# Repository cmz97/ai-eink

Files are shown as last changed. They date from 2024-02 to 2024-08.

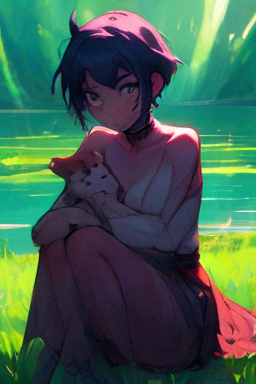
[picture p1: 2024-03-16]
temp-anime-flexible.png

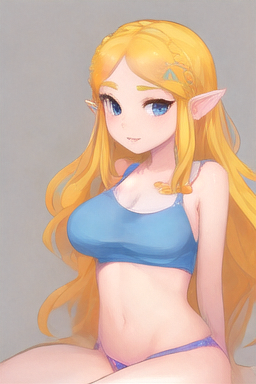
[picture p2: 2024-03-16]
temp-anime-zelda.png

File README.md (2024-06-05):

# ai-eink

# System 
sudo apt-get install sysstat

# Device Tree Overlay
force_turbo=1
dtoverlay=uart3

# NFC
NFC Driver: https://github.com/2pecshy/eeprom-ST25DV-linux-driver
sudo apt install -y python3-libcamera python3-kms++ libcap-dev

# Drivers
## Camera 
sudo wget https://datasheets.raspberrypi.org/cmio/dt-blob-cam1.bin -O /boot/dt-blob.bin
libcamera-still -q 80 -o test.jpg

For OS Lite 
Open Terminal and enter "sudo nano /boot/config.txt"
Scroll down to the line that reads "camera_auto_detect=1" and change it to "camera_auto_detect=0"
On the next line, enter "dtoverlay=imx219"
Reboot

## Speakers
https://github.com/HinTak/seeed-voicecard
sudo aplay -Dhw:0 test.wav
sudo arecord -D hw:0,0 -f S32_LE -r 16000 -c 2 test.wav
https://www.waveshare.com/wiki/WM8960_Audio_HAT
sudo alsactl store

## Pi-PICO
ampy --port /dev/tty.usbmodem112401 put main.py

## Radxa
sudo apt-get install python3-dev spidev
sudo apt-get update
sudo apt-get install python3-libgpiod

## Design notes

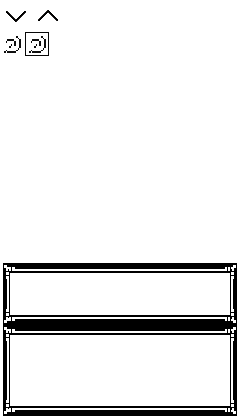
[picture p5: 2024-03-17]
ui_sheet.png

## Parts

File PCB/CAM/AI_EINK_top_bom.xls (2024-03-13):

Comment | Designator | Footprint | LCSC Part #
 | J2 JP6 SJ1 SJ2 SJ3 SJ4 SJ5 SJ6
MK-12C02-G020 | S1
DNP SPW2430HR5H-B | LEFTMIC RIGHTMIC
0.01 | R12 | 1206
0.1uF | C4 C16 C18 | 0805_10MGAP
0.1uF | C25 C27 C47 C48 C49 C50 C51 C58 | 0603-NO
0.47 | R9 | RESC1608X60
0.47uF | C20 | 0603-CAP
1.0uF | C19 | 0603-CAP
1.0uF | C22 | 1206-CAP
1.0uF | C30 | 0603-NO
1.1k | R7 R21 | 0603-RES
1.87M | R3 | 0805-NO
1.87M (TPA2005D1DRBR) | R1 | _0805MP
1K | R5 R20 | 0805-NO
1K | R23 | 0603-RES
1k | R8 R10 R28 | R0603
1nF | C36 C37 C38 C39 C40 | 603
1uF | C5 C8 C9 C10 C11 C12 C13 C14 C15 | CAPC1608X85
2.2uF | C2 | 0805-NO
2.2uF+ | C66 | 0805-NO
4.7K | R15 R18 | 0603-RES
4.7uF/50V | C17 | 0805_10MGAP
5VBOOST | LED2 | CHIPLED_0805_NOOUTLINE
6.8uH | L1 | INDUCTOR_5X5MM_TDK_VLC5045
10K | R11 | RESC1608X60
10K | R14 | 0603-NO
10K | R29 R33 | 0603-RES
10uF | C1 C3 C7 | 0805-NO
10uF | C21 C23 | 0805-CAP
10uF | C24 C26 C31 C32 C33 C34 C35 C45 C46 C56 C57 C65 | 0805-NO
24MHz 3.3V Oscillator | OSC1 | OSC_3.2X2.5MM
33pF | C52 C53 C54 C55 | 0603-NO
100k | R24 R31 | 0603-RES
100pF | C63 C64 | 0603-NO
100uF | C6 | C1210
120o | FB9 FB10 | 0805-NO
180 | R22 | 0603-RES
200K | R4 R13 | 0805-NO
340K (RTT053403FTP) | R2 | _0805MP
590 | R6 R19 | 0603-RES
524372471 | J3 | CON_524372471_MOL
ACT (MHT192JGCT) | D1 | LED-0603@1
ASPI-0403S-100M-T | L2 | IND_ASPI-0403S-100M-T
BLM18HE152SN1D | FL1 FL2 | BEADC1608X95N
BQ24075 | U4 | PVQFN-N16
BQ27441DRZR-G1A | U3 | PDSO-N12
CHARGING FC-1608B1-470 | D5 | LED-0603
CMS-18138A-SP | LS1 | CUI_CMS-18138A-SP
DF30FC-24DP-0.4V(81) | OV5647 | DF30FC-24DP
DF40C-100DS-0.4V(51) | RPI-CM1 | RPI-CM4
DF40C-100DS-0.4V(51) | RPI-CM1-2 | RPI-CM4
ECS-3225MV | OSC2 | OSC_3.2X2.5MM
FERRITE | FB4 | 0805-NO
Ferrite | FB3 | 0805-NO
MBR0530 | D2 D3 D4 | SOD3716X135N
MC74VHC1G14DFT1G | U2 | SOT65P210X110-5N
MMUN2133LT1G | T1 | SC59-BEC
NFC_ANTENNA_25X15 | ANT1 | NFCANT_25X15
PMIC | D6 | LED-0603
SI1308EDL-T1-GE3 | Q1 | SOT65P210X110-3N
ST25DVXX_TSSOP | RF1 | TSSOP8-4.4MM
SYS_POW (19-213/Y2C-CQ2R2L/3T(CY)) | LED3 | LED-0603
TEST-POINT3 | GND GND13 GND22 GND25 GND26 GND27 RPIBOOT RPIBOOT1 RPIBOOT2 RPIBOOT3 RPIBOOT4 RPIBOOT5 | PAD.03X.03
TLV74315 | U6 | SOT23-5
TLV74328 | U5 | SOT23-5
TPS61090RSAR | U1 | PVQFN-16
WM8960 | IC3 | QFN32_5MM
XL-2012VRC | LOW_BATT | CHIPLED_0805_NOOUTLINE

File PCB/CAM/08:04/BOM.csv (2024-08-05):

Comment | Designator | Footprint | LCSC Part #
1uF | C5 C14 | CAPC1005X60
10K | R18 | RESC1005X40
10k | R4 | RESC1005X40
10uF | C8 C9 C17 | CAPC1005X60
22uF | C1 | CAPC1005X60
22uF | C2 | CAPC1608X85
22uF | C3 | CAPC1005X60
100K | R1 R3 | RESC1005X40
120pF | C4 | CAPC1005X60
450K | R2 | RESC1005X40
ESP32-S3-WROOM | U5 | S3-WROOM32
KLM8G1GETF-B041KLMBG2JENB-B041_SAM | U1 | KLMBG2JENB-B041_SAM
MIC5504-1.8YMT-TRTDFN1010-4LD-PL-2_MCH | U2 | TDFN1010-4LD-PL-2_MCH
RKB2 | SW1 SW2 | BTN_RKB2_4.6X2.8
SDER041H-2R2MS | L1 | INDUCTOR_4X4MM_SRP0415
SM04B-SRSS-TBCONN_SM04B-SRSS-TB_JST | J2 J3 | CONN_SM04B-SRSS-TB_JST
SM08B-SRSS-TB(LF)(SN)CONN_SM08B-SRSS-TB(LF)(SN)_JST | J1 | CONN_SM08B-SRSS-TB(LF)(SN)_JST
TPS6282X | IC2 | VSON_6
green | D1 | CHIPLED_0603_NOOUTLINE
DF40C-100DP-0.4V(51) | JA JB | HIROSE_DF40C-100DP-0.4V(51)
DNP | TP_1V8 TP_3V3 TP_5V TP_DATA0 TP_EMMC_CLK TP_EMMC_CMD TP_GND | PAD.03X.03

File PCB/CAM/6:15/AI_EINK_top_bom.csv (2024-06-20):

Comment | Designator | Footprint | LCSC Part #
0.01 | R12 | 1206
0.1uF | C4 C24 C31 | CAPC1005X60
0.1uF | C42 | CAPC1608X85
0.1uF | C43 C44 C47 C48 C49 C50 C58 C67 C69 C71 C72 C73 C74 C77 | CAPC1005X60
0.47 | R9 | RESC1005X40
0.47uF | C20 | CAPC1005X60
1-2199119-5 OR C841645 | M.2KEYM(NGFF) | TE_1-2199119-5
1.0uF | C19 C30 C75 C76 | CAPC1005X60
1.1k | R7 | RESC1005X40
1.87M | R3 | RESC1005X40
1.87M (TPA2005D1DRBR) | R1 | RESC1005X40
1K | R5 R14 R20 R23 | RESC1005X40
1k | R8 R10 R34 R35 | RESC1005X40
1uF | C5 C8 C9 C10 C11 C12 C13 C14 C15 C16 C34 C35 | CAPC1005X60
2.2uF | C2 | CAPC1005X60
2.2uF+ | C66 | CAPC1005X60
4.7K | R15 R18 R25 R26 R40 R42 | RESC1005X40
4.7k | R38 | RESC1005X40
4.7uF | C18 | CAPC1608X85
4.7uF | C29 | CAPC1005X60
4.7uF/50V | C17 | CAPC1005X60
5.1K | R19 | RESC1005X40
5.1k | R21 | RESC1005X40
6.8uH C36410 | L1 | INDUCTOR_5X5MM_TDK_VLC5045
6.57k | R44 | RESC1005X40
10K | R11 R33 R43 | RESC1005X40
10k | R16 R17 R27 R28 R37 R39 | RESC1005X40
10uF | C1 C3 C7 C21 C22 C23 C26 C28 C32 C33 C36 C40 C45 C46 C53 C59 C60 C61 C62 C65 C68 C79 C80 | CAPC1005X60
15p | C82 C83 | CAPC1005X60
27 | R31 R32 | RESC1005X40
27pF | C27 | CAPC1005X60
36k | R30 | RESC1005X40
47K | R41 | RESC1005X40
100k | R24 | RESC1005X40
100pF | C63 C64 | CAPC1005X60
100uF | C6 C25 | C1210
180 | R22 | RESC1005X40
200K | R4 R13 R36 | RESC1005X40
340K (RTT053403FTP) | R2 | RESC1005X40
590 | R6 | RESC1005X40
524372471 | EINK_524352471 | CON_524372471_MOL
ABM8-272-T3 | Y1 | ABM8272T3
ACT (MHT192JGCT) | D1 | LED-0603@1
AP2112-3.3K | U10 U11 U15 | SOT23-5
BM04B-SRSS-TBCONN4_BM04B-SRSS_JST | H2 J4 J5 | CONN4_BM04B-SRSS_JST
BQ24075 | U4 | PVQFN-N16
BQ27441DRZR-G1A | U3 | PDSO-N12
C233266 | U12 | XDCR_SPU0410LR5H-QB
C262642 | CAMERA | CON_524372271_MOL
C393939 | J2 | USB-C-16P
CHARGING FC-1608B1-470 | D5 | LED-0603
CMS-18138A-SP | LS1 | CUI_CMS-18138A-SP
DF40C-100DS-0.4V(51) | RPI-CM1 | RPI-CM4
DMG2307L | Q2 | SOT96P240X110-3N
DNP | GND13 GND26 GND27 GND34 RPIBOOT RPIBOOT1 RPIBOOT2 RPIBOOT3 RPIBOOT4 | PAD.03X.03
DNP | SJ1 SJ6 | PAD-JUMPER-2-NC_BY_TRACE_YES_SILK
DNP | USB_BOOT_N | PAD.03X.03
DRV2605LDGSR | U25 | SOP50P490X110-10N
ECS-3225MV | OSC2 | OSC_3.2X2.5MM
EMC2301-1-ACZL-TRMSOP8_MC_MCH-L | U9 | MSOP8_MC_MCH-L
EVQ-P7A01P | BUD BUP BUS | SW_EVQ-P7A01P
FERRITE_BEAD | FB1 FB2 FB3 FB5 | BEADC1608X95N
FNR5012S100MT 10uH | L3 | IND_LQH5BPN2R2NT0L
LED_RED | LED2 LOW_BATT | LEDC1608X65N_RND-R
LIS3MDL | IC1 | LGA12_2X2MM
LSM6DS3 | U6 | LGA-14L
MBR0530 | D2 D3 D4 | SOD3716X135N
MC74VHC1G14DFT1G | U2 | SOT65P210X110-5N
MC74VHC1G14DFT1G OR C66196 | U5 | SOT65P210X110-5N
MMUN2133LT1G | T1 | SC59-BEC
NMOS_C7465427 | Q3 Q4 | SOT23
OPA344 | U14 | SOT23-5
PMIC | D6 D7 | LED-0603
RP2040TR13QFN56_7X7_RPI | C2040 | QFN56_7X7_RPI
SI1308EDL-T1-GE3 | Q1 | SOT65P210X110-3N
SM03B-SRSS-TBCONN_SM03B-SRSS-TB_JST | J1 | CONN_SM03B-SRSS-TB_JST
SM04B-SRSS-TBCONN_SM04B-SRSS-TB_JST | J6 | CONN_SM04B-SRSS-TB_JST
SN74LVC244ARWPRRWP0020A | U7 | RWP0020A
SYS_POW (19-213/Y2C-CQ2R2L/3T(CY)) | LED3 | LED-0603
TEST-POINT3 | RPIBOOT5 | PAD.03X.03
TPD1E1B04DPYRDPY2_TEX | U17 U18 U19 U20 U21 U22 U23 U24 | DPY2_TEX
TPD4EUSB30DQARDQA10 | U13 | DQA10
TPS61092RSAR | U1 | PVQFN-16
TS3USB30RSWR | USB2.0MUX | 10-UFQFN
W25Q16JVUXIQ_TR | U16 | PSON50P300X200X60-9N
WM8960 | IC3 | QFN32_5MM

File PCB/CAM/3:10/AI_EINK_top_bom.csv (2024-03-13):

Comment | Designator | Footprint | LCSC Part #
0.01 | R12 | 1206
0.1uF | C4 C27 C42 C43 C44 C47 C48 C49 C50 C58 C67 C69 C70 C71 C72 C73 C74 C77 C78 C81 | CAPC1608X85
0.47 | R9 | R0603
0.47uF | C20 | CAPC1608X85
1.0uF | C19 C22 C25 C30 C75 C76 | CAPC1608X85
1.1k | R7 | R0603
1.87M | R3 | R0603
1.87M (TPA2005D1DRBR) | R1 | R0603
1K | R5 R14 R20 R23 | R0603
1k | R8 R10 R34 R35 | R0603
1uF | C5 C8 C9 C10 C11 C12 C13 C14 C15 C16 | CAPC1608X85
2.2uF | C2 | CAPC1608X85
2.2uF+ | C66 | CAPC1608X85
2.5A/30V | Q2 | SOT23-3
4.7K | R15 R18 | R0603
4.7uF | C18 | CAPC1608X85
4.7uF/50V | C17 | CAPC1608X85
5VBOOST | LED2 | CHIPLED_0805_NOOUTLINE
6.8uH | L1 | INDUCTOR_5X5MM_TDK_VLC5045
10K | R11 R29 R33 | R0603
10k | R16 R17 R28 | R0603
10uF | C1 C3 C7 C21 C23 C24 C26 C28 C29 C31 C32 C33 C34 C35 C36 C37 C38 C39 C45 C46 C57 C59 C60 C61 C62 C65 C68 C79 C80 | CAPC1608X85
15p | C82 C83 | CAPC1608X85
24MHz 3.3V Oscillator | OSC1 | OSC_3.2X2.5MM
27 | R31 R32 | R0603
33pF | C52 C54 | CAPC1608X85
36k | R30 | R0603
100k | R24 | R0603
100pF | C63 C64 | CAPC1608X85
100uF | C6 | C1210
120o | FB9 FB10 | 0805-NO
180 | R22 | R0603
200K | R4 R13 R36 R37 | R0603
340K (RTT053403FTP) | R2 | R0603
590 | R6 | R0603
524372471 | J3 | CON_524372471_MOL
ABM8-272-T3 | Y1 | ABM8272T3
ACT (MHT192JGCT) | D1 | LED-0603@1
AP2112-3.3K | U10 U11 | SOT23-5
ASPI-0403S-100M-T | L2 | IND_ASPI-0403S-100M-T
BLM18HE152SN1D | FL3 FL4 FL5 | BEADC1608X95N
BM04B-GHS-TBT(LF)(SN)(N) | J1 | JST_BM04B-GHS-TBT(LF)(SN)(N)
BQ24075 | U4 | PVQFN-N16
BQ27441DRZR-G1A | U3 | PDSO-N12
C393939 | J2 | USB-C-16P
C963206 | S1 | SWITCH-SPST-SMD-A
CHARGING FC-1608B1-470 | D5 | LED-0603
CMS-18138A-SP | LS1 | CUI_CMS-18138A-SP
DF30FC-24DS-0.4V(82)CONN_DF30FC-24DS-0.4V(82)_HIR | OV5674 | CONN_DF30FC-24DS-0.4V(82)_HIR
DF40C-100DS-0.4V(51) | RPI-CM1 | RPI-CM4
DF40C-100DS-0.4V(51) | RPI-CM2 | RPI-CM4
DNP | GND GND13 GND22 GND25 GND26 GND27 GND34 RPIBOOT RPIBOOT1 RPIBOOT2 RPIBOOT3 RPIBOOT4 | PAD.03X.03
DNP | SJ1 | PAD-JUMPER-2-NC_BY_TRACE_YES_SILK
DNP | SJ2 SJ3 | PAD-JUMPER-3-2OF3_NC_BY_TRACE_YES_SILK_FULL_BOX
DNP | SJ6 | PAD-JUMPER-2-NC_BY_TRACE_YES_SILK
DNP | USB_BOOT_N | PAD.03X.03
ECS-3225MV | OSC2 | OSC_3.2X2.5MM
EMC2301-1-ACZL-TRMSOP8_MC_MCH-L | U9 | MSOP8_MC_MCH-L
Ferrite | FB2 | 0805
Ferrite | FB3 | 0805-NO
Ferrite | FB5 | 0805
MBR0530 | D2 D3 D4 | SOD3716X135N
MC74VHC1G14DFT1G | U2 | SOT65P210X110-5N
MMUN2133LT1G | T1 | SC59-BEC
NFC_ANTENNA_25X15 | ANT1 | NFCANT_25X15
PMIC | D6 D7 | LED-0603
RP2040TR13QFN56_7X7_RPI | C2040 | QFN56_7X7_RPI
S2B-PH-SM4-TB | JP6 | JST-2-SMD
SI1308EDL-T1-GE3 | Q1 | SOT65P210X110-3N
SPU0410LR5H-QB | U12 | XDCR_SPU0410LR5H-QB
ST25DV64K-IER6S3SOIC_IER6S3_STM | U8 | SOIC_IER6S3_STM
SYS_POW (19-213/Y2C-CQ2R2L/3T(CY)) | LED3 | LED-0603
TEST-POINT3 | RPIBOOT5 | PAD.03X.03
TLV74315 | U6 | SOT23-5
TLV74318PDBVRDBV0005A_L | U7 | DBV0005A_L
TLV74328 | U5 | SOT23-5
TPS61090RSAR | U1 | PVQFN-16
W25Q128JVBIQTFBGA_128JVBIQ_WIN | SPI_FLASH_SAM | TFBGA_128JVBIQ_WIN
WM8960 | IC3 | QFN32_5MM
XL-2012VRC | LOW_BATT | CHIPLED_0805_NOOUTLINE

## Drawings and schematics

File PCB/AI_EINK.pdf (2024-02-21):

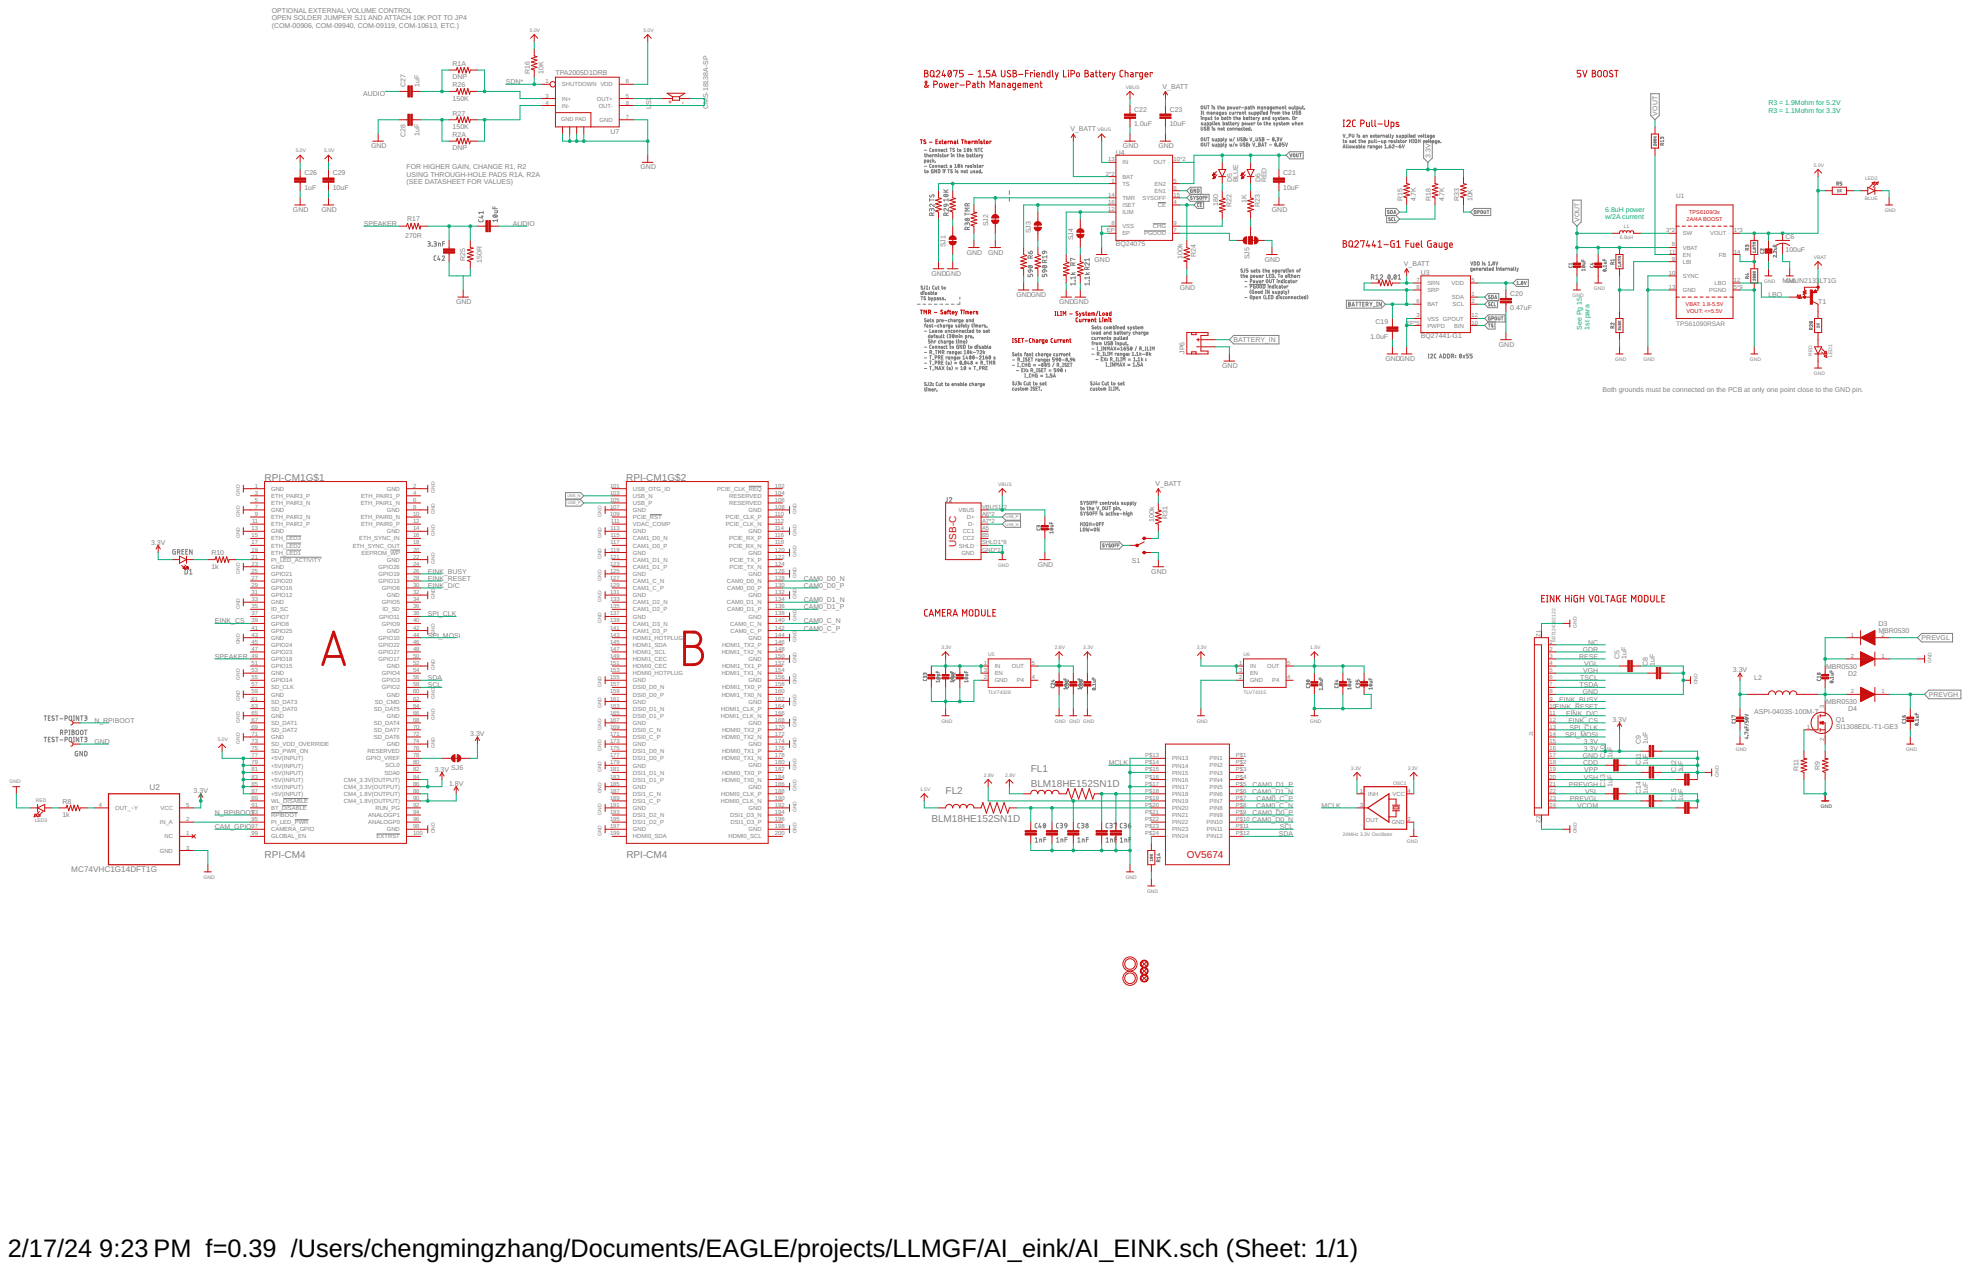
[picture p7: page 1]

OPEN SOLDER JUMPER SJ1 AND ATTACH 10K POT TO JP4 OPTIONAL EXTERNAL VOLUME CONTROL
(COM-00906, COM-09940, COM-09119, COM-10613, ETC.)

FOR HIGHER GAIN, CHANGE R1, R2 USING THROUGH-HOLE PADS R1A, R2A
(SEE DATASHEET FOR VALUES)

Both grounds must be connected on the PCB at only one point close to the GND pin.

GND GND GND GND GND GND GND GND GND GND 1k

GND GND GND GND GND GND GND GND GND GND GND

GND GND GND GND GND GND GND

GND GND GND GND GND GND GND GND

2/17/24 9:23 PM f=0.39 /Users/chengmingzhang/Documents/EAGLE/projects/LLMGF/AI_eink/AI_EINK.sch (Sheet: 1/1)

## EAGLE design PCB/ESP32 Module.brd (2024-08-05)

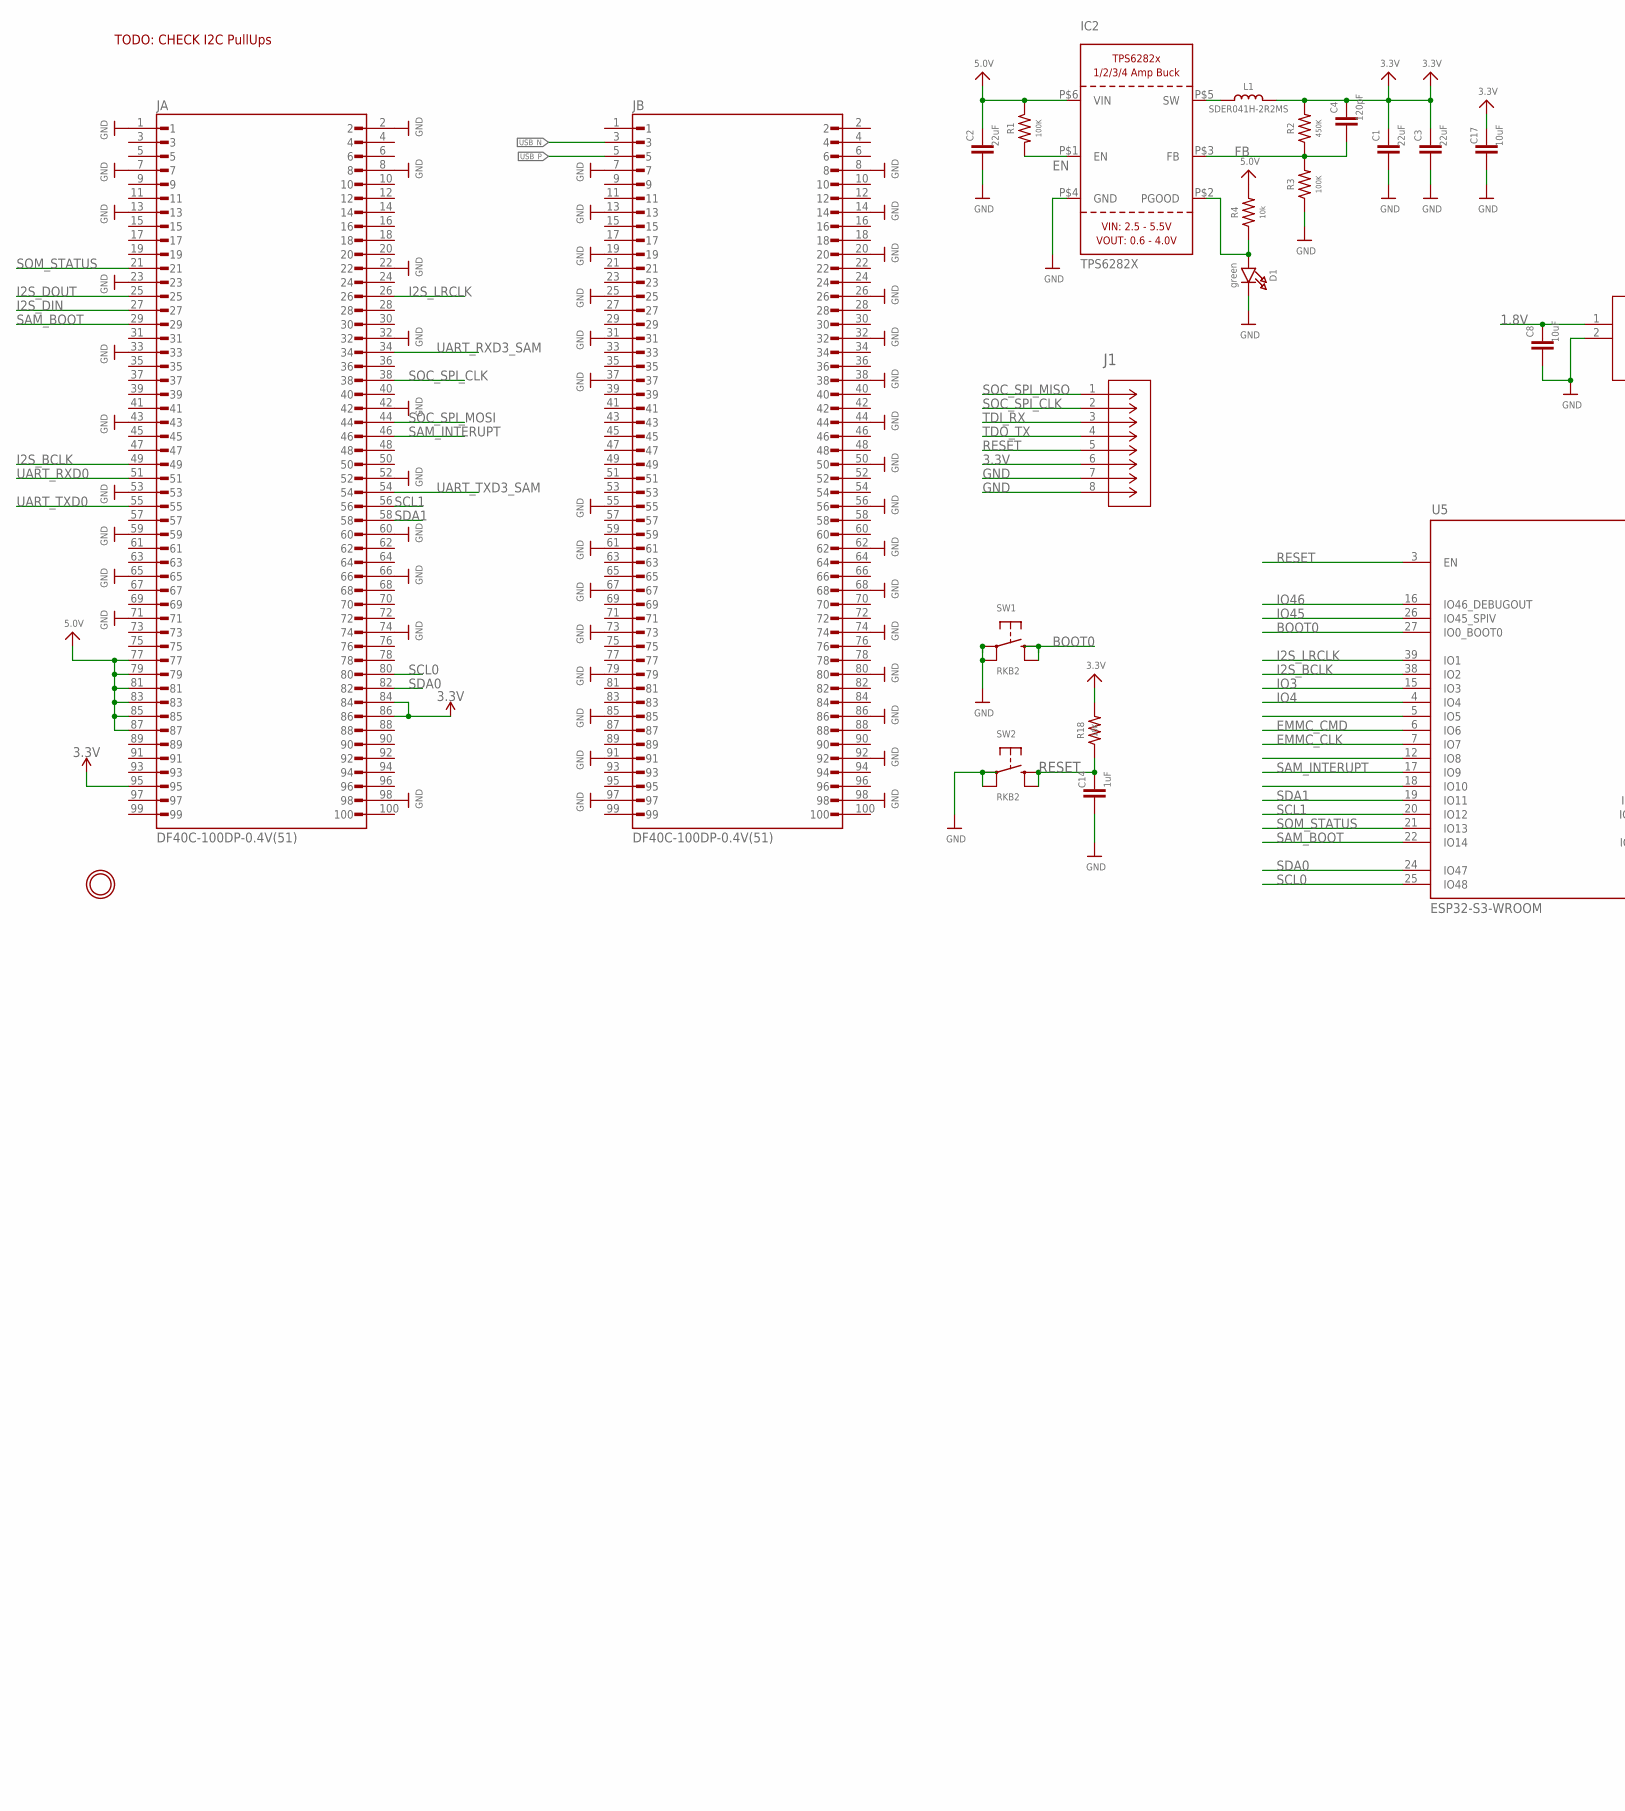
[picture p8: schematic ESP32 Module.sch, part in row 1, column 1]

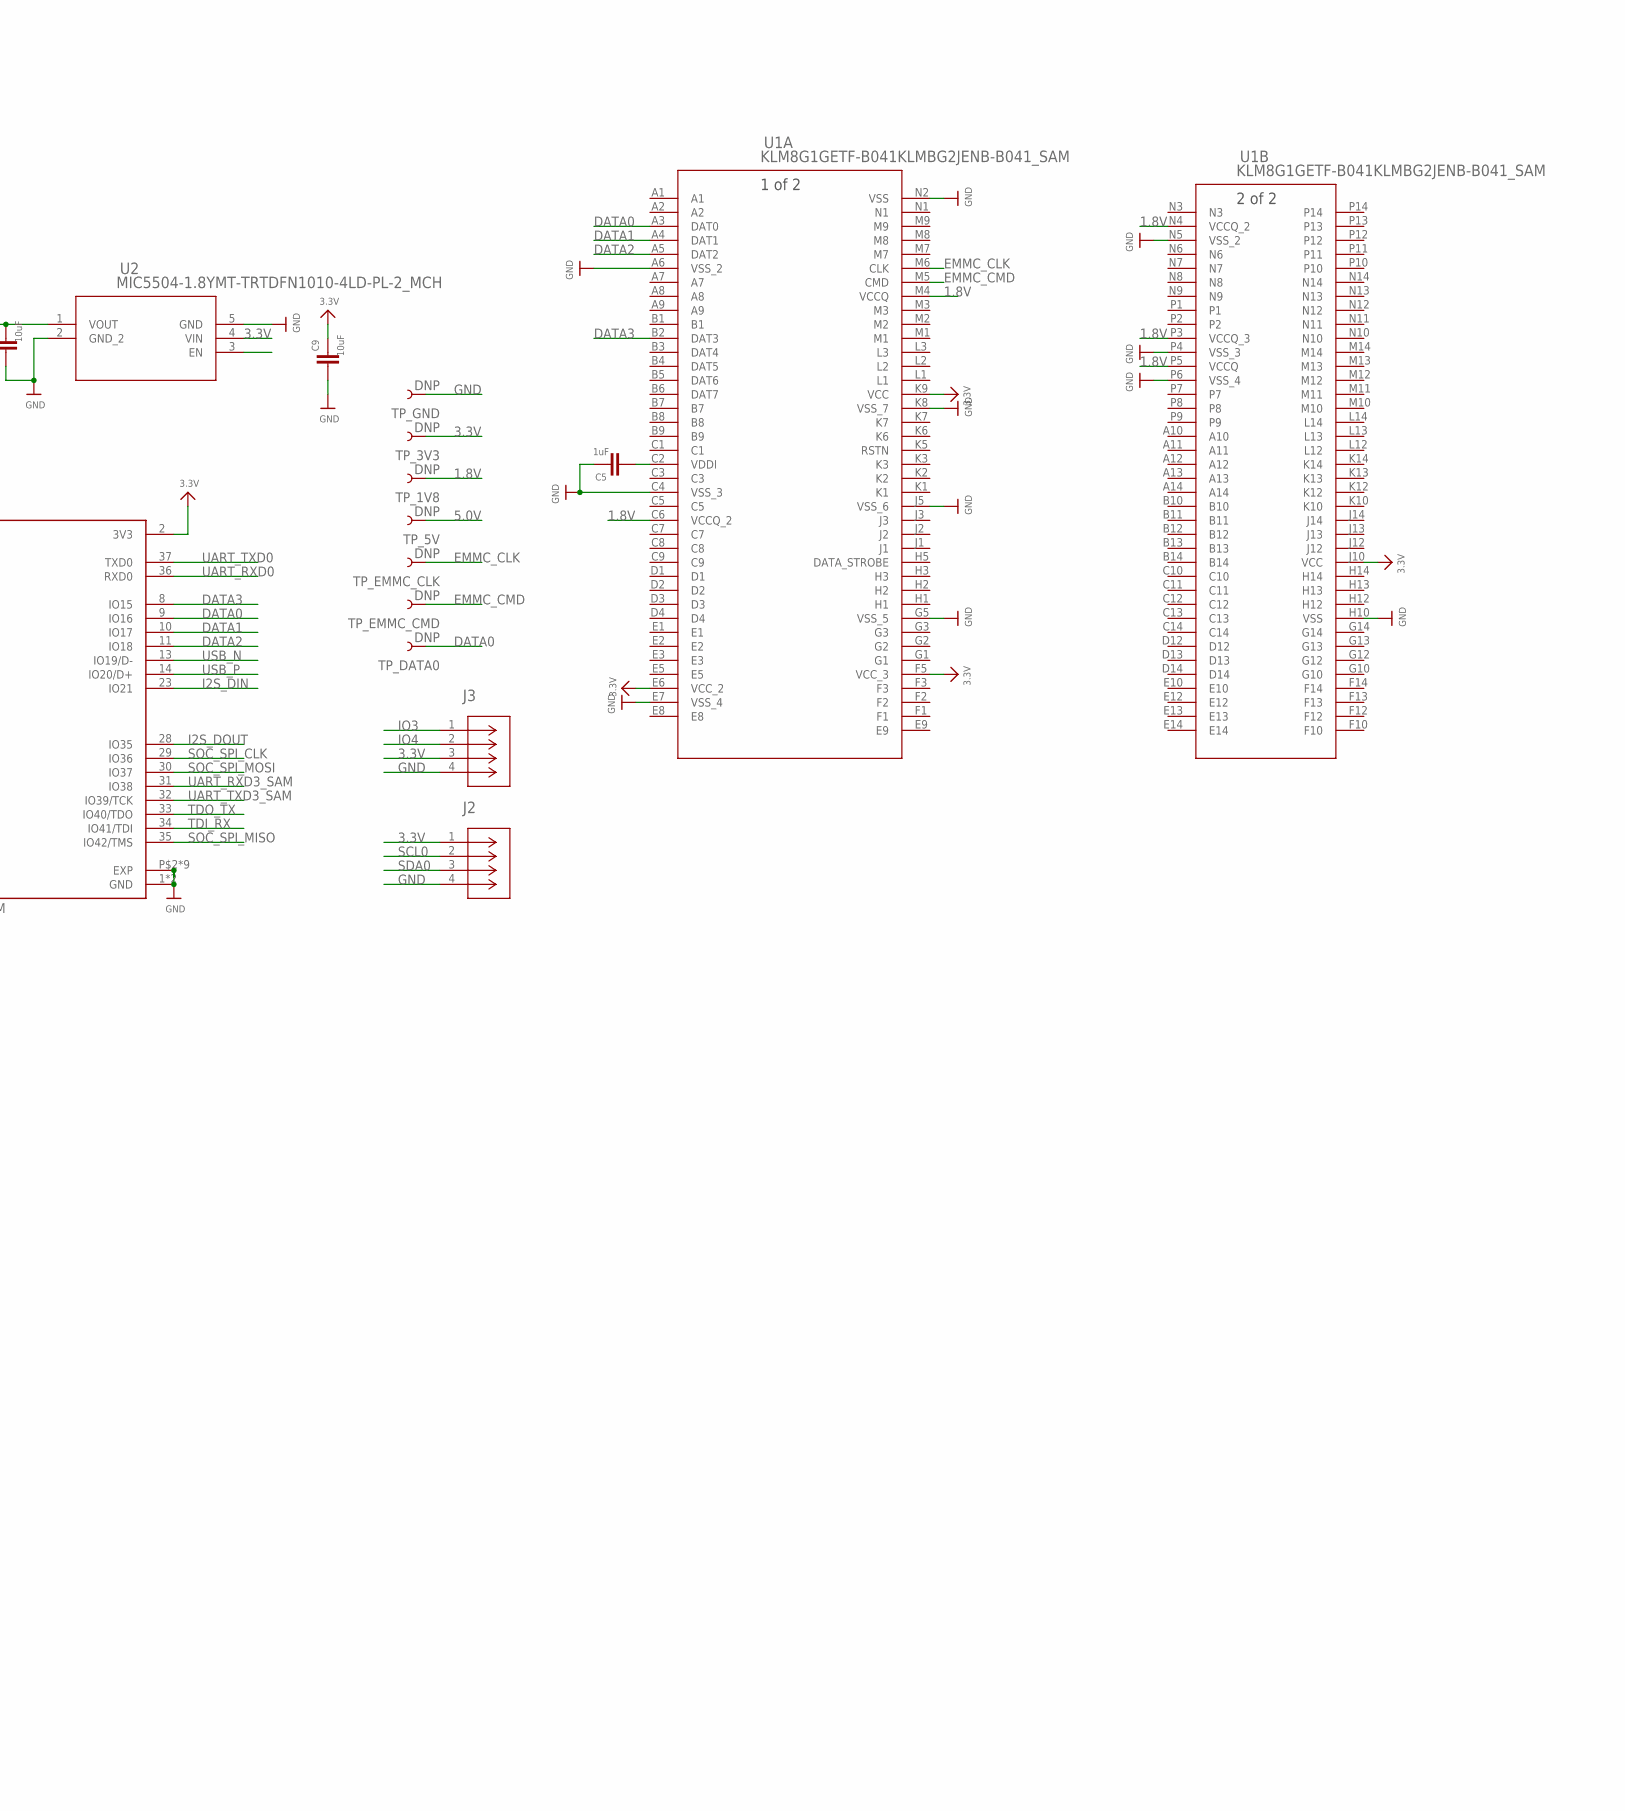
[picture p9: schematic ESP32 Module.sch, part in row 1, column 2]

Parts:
C1, C3: 22uF; CAPC1005X60
C2: 22uF; CAPC1608X85
C4: 120pF; CAPC1005X60
C5, C14: 1uF; CAPC1005X60
C8, C9, C17: 10uF; CAPC1005X60
D1: green; CHIPLED_0603_NOOUTLINE
IC2: TPS6282X; VSON_6
J1: SM08B-SRSS-TB(LF)(SN)CONN_SM08B-SRSS-TB(LF)(SN)_J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; CONN_SM08B-SRSS-TB(LF)(SN)_JST
J2, J3: SM04B-SRSS-TBCONN_SM04B-SRSS-TB_JST; CONN_SM04B-SRSS-TB_JST
JA: DF40C-100DP-0.4V(51); HIROSE_DF40C-100DP-0.4V(51)
JB: DF40C-100DP-0.4V(51); HIROSE_DF40C-100DP-0.4V(51)
L1: SDER041H-2R2MS; INDUCTOR_4X4MM_SRP0415
R1, R3: 100K; RESC1005X40
R2: 450K; RESC1005X40
R4: 10k; RESC1005X40
R18: 10K; RESC1005X40
SW1, SW2: RKB2; BTN_RKB2_4.6X2.8
TP_1V8, TP_3V3, TP_5V: DNP; PAD.03X.03
TP_DATA0: DNP; PAD.03X.03
TP_EMMC_CLK: DNP; PAD.03X.03
TP_EMMC_CMD: DNP; PAD.03X.03
TP_GND: DNP; PAD.03X.03
U1: KLM8G1GETF-B041KLMBG2JENB-B041_SAM; KLMBG2JENB-B041_SAM
U2: MIC5504-1.8YMT-TRTDFN1010-4LD-PL-2_MCH; TDFN1010-4LD-PL-2_MCH
U5: ESP32-S3-WROOM; S3-WROOM32
U$2, U$120: MOUNTINGHOLE2.5; MOUNTINGHOLE_2.5_PLATED

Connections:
1.8V: C8.1, TP_1V8.P$1, U1.C6 (VCCQ_2), U1.M4 (VCCQ), U1.N4 (VCCQ_2), U1.P3 (VCCQ_3), U1.P5 (VCCQ), U2.1 (VOUT)
3.3V: C1.1, C3.1, C4.1, C9.1, C17.1, J1.6, J2.1, J3.3, JA.84, JA.86, JA.95, L1.P$2 (2), R2.2, R18.2, TP_3V3.P$1, U1.E6 (VCC_2), U1.F5 (VCC_3), U1.J10 (VCC), U1.K9 (VCC), U2.4 (VIN), U5.2 (3V3)
5.0V: C2.1, IC2.P$6 (VIN), JA.77, JA.79, JA.81, JA.83, JA.85, JA.87, R1.1, R4.2, TP_5V.P$1
BOOT0: SW1.B (S), SW1.B' (S1), U5.27 (IO0_BOOT0)
DATA0: TP_DATA0.P$1, U1.A3 (DAT0), U5.9 (IO16)
DATA1: U1.A4 (DAT1), U5.10 (IO17)
DATA2: U1.A5 (DAT2), U5.11 (IO18)
DATA3: U1.B2 (DAT3), U5.8 (IO15)
EMMC_CLK: TP_EMMC_CLK.P$1, U1.M6 (CLK), U5.7 (IO7)
EMMC_CMD: TP_EMMC_CMD.P$1, U1.M5 (CMD), U5.6 (IO6)
EN: IC2.P$1 (EN), R1.2
FB: C4.2, IC2.P$3 (FB), R2.1, R3.2
GND: C1.2, C2.2, C3.2, C5.1, C8.2, C9.2, C14.2, C17.2, D1.C, IC2.P$4 (GND), J1.7, J1.8, J2.4, J3.4, JA.1, JA.2, JA.7, JA.8, JA.13, JA.22, JA.23, JA.32, JA.33, JA.42, JA.43, JA.52, JA.53, JA.59, JA.60, JA.65, JA.66, JA.71, JA.74, JA.98, JB.7, JB.8, JB.13, JB.14, JB.19, JB.20, JB.25, JB.26, JB.31, JB.32, JB.37, JB.38, JB.44, JB.50, JB.55, JB.56, JB.61, JB.62, JB.67, JB.68, JB.73, JB.74, JB.79, JB.80, JB.85, JB.86, JB.91, JB.92, JB.97, JB.98, R3.1, SW1.A, SW1.A' (P1), SW2.A, SW2.A' (P1), TP_GND.P$1, U1.A6 (VSS_2), U1.C4 (VSS_3), U1.E7 (VSS_4), U1.G5 (VSS_5), U1.H10 (VSS), U1.J5 (VSS_6), U1.K8 (VSS_7), U1.N2 (VSS), U1.N5 (VSS_2), U1.P4 (VSS_3), U1.P6 (VSS_4), U2.2 (GND_2), U2.5 (GND), U5.1 (GND), U5.40 (GND), U5.P$2 (EXP), U5.P$3 (EXP), U5.P$4 (EXP), U5.P$5 (EXP), U5.P$6 (EXP), U5.P$7 (EXP), U5.P$8 (EXP), U5.P$9 (EXP), U5.P$10 (EXP)
I2S_BCLK: JA.49, U5.38 (IO2)
I2S_DIN: JA.27, U5.23 (IO21)
I2S_DOUT: JA.25, U5.28 (IO35)
I2S_LRCLK: JA.26, U5.39 (IO1)
IO3: J3.1, U5.15 (IO3)
IO4: J3.2, U5.4 (IO4)
IO10: U5.18 (IO10)
IO45: U5.26 (IO45_SPIV)
IO46: U5.16 (IO46_DEBUGOUT)
unnamed: IC2.P$5 (SW), L1.P$1 (1)
unnamed: D1.A, IC2.P$2 (PGOOD), R4.1
unnamed: C5.2, U1.C2 (VDDI)
RESET: C14.1, J1.5, R18.1, SW2.B (S), SW2.B' (S1), U5.3 (EN)
SAM_BOOT: JA.29, U5.22 (IO14)
SAM_INTERUPT: JA.46, U5.17 (IO9)
SCL0: J2.2, JA.80, U5.25 (IO48)
SCL1: JA.56, U5.20 (IO12)
SDA0: J2.3, JA.82, U5.24 (IO47)
SDA1: JA.58, U5.19 (IO11)
SOC_SPI_CLK: J1.2, JA.38, U5.29 (IO36)
SOC_SPI_MISO: J1.1, U5.35 (IO42/TMS)
SOC_SPI_MOSI: JA.44, U5.30 (IO37)
SOM_STATUS: JA.21, U5.21 (IO13)
TDI_RX: J1.3, U5.34 (IO41/TDI)
TDO_TX: J1.4, U5.33 (IO40/TDO)
UART_RXD0: JA.51, U5.36 (RXD0)
UART_RXD3_SAM: JA.34, U5.31 (IO38)
UART_TXD0: JA.55, U5.37 (TXD0)
UART_TXD3_SAM: JA.54, U5.32 (IO39/TCK)
USB_N: JB.3, U5.13 (IO19/D-)
USB_P: JB.5, U5.14 (IO20/D+)

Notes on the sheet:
TODO: CHECK I2C PullUps

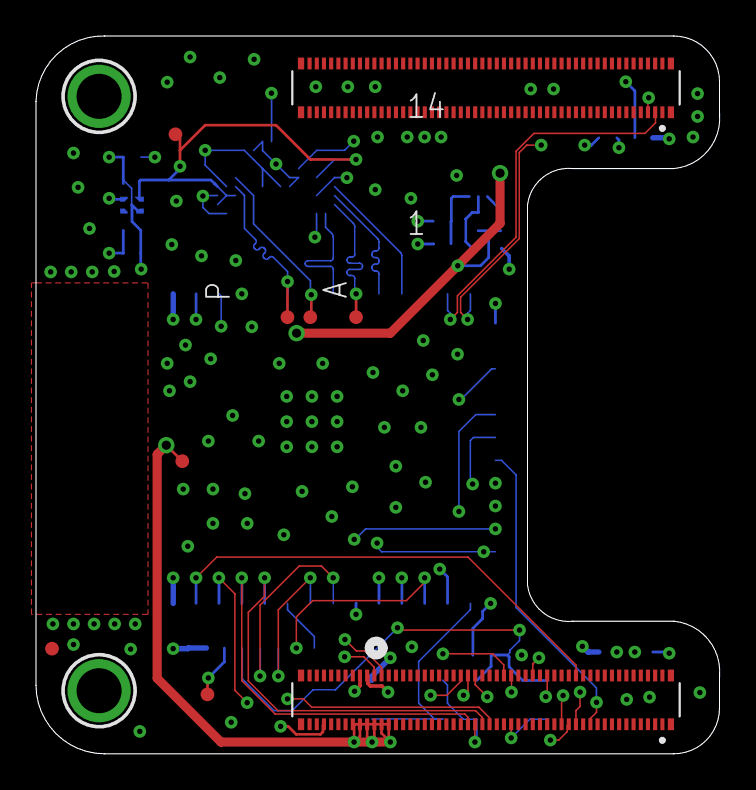
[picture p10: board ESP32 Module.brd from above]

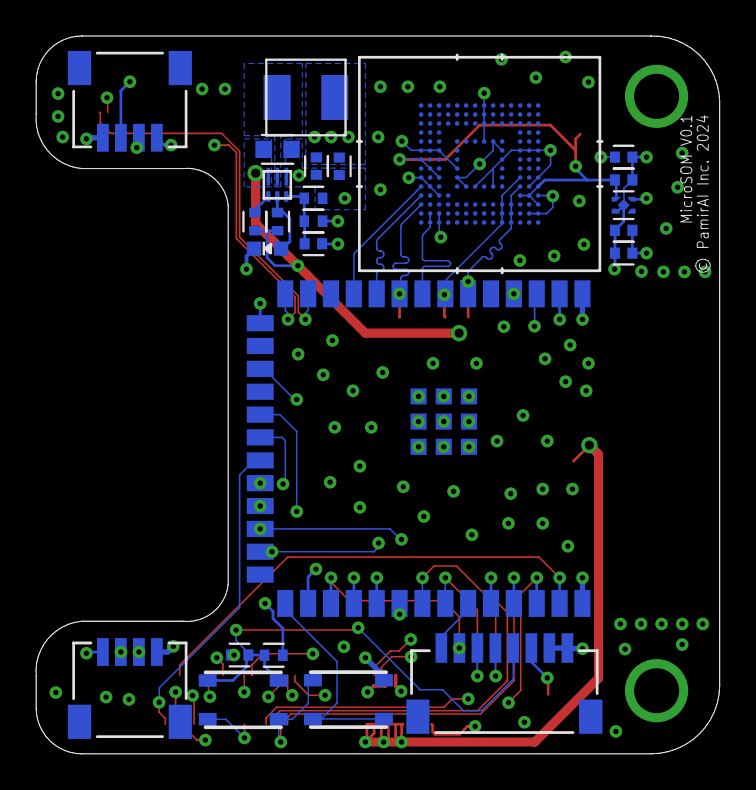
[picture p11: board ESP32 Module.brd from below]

Board: 4 copper layers, 38.0 x 39.9 mm, 36 parts (25 on the bottom side), 41 nets.

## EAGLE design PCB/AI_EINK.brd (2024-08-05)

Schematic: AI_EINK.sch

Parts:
BUD: EVQ-P7A01P; SW_EVQ-P7A01P
BUP: EVQ-P7A01P; SW_EVQ-P7A01P
BUS: EVQ-P7A01P; SW_EVQ-P7A01P
C1, C3, C7, C21, C22, C23, C26, C28, C32, C33, C36, C39, C40, C45, C46, C53, C54, C55, C59, C60, C61, C62, C65, C68, C79, C80: 10uF; CAPC1005X60
C2: 2.2uF; CAPC1005X60
C4, C24, C31, C37, C38, C43, C44, C47, C48, C49, C50, C58, C67, C69, C71, C72, C73, C74, C77: 0.1uF; CAPC1005X60
C5, C8, C9, C10, C11, C12, C13, C14, C15, C16, C34, C35: 1uF; CAPC1005X60
C6, C25: 100uF; C1210
C17: 4.7uF/50V; CAPC1005X60
C18: 4.7uF; CAPC1608X85
C19, C30, C75, C76: 1.0uF; CAPC1005X60
C20: 0.47uF; CAPC1005X60
C27: 27pF; CAPC1005X60
C29: 4.7uF; CAPC1005X60
C42: 0.1uF; CAPC1608X85
C52, C57: 220pF; CAPC1005X60
C63, C64: 100pF; CAPC1005X60
C66: 2.2uF+; CAPC1005X60
C82, C83: 15p; CAPC1005X60
C2040: RP2040TR13QFN56_7X7_RPI; QFN56_7X7_RPI
CAMERA: C262642; CON_524372271_MOL
D1: ACT (MHT192JGCT); LED-0603@1
D2, D3, D4: MBR0530; SOD3716X135N
D5: CHARGING FC-1608B1-470; LED-0603
D6, D7: PMIC; LED-0603
DISPLAY: C262642; CON_524372271_MOL
EINK_524352471: 524372471; CON_524372471_MOL
FB1, FB2, FB3, FB5: FERRITE_BEAD; BEADC1608X95N
FB4, FB7: 120o; BEADC1608X95N
GND, GND7, GND13, GND22, GND26, GND27, GND34, GND36, GND37, GND40, GND41, GND42: DNP; PAD.03X.03
H2: BM04B-SRSS-TBCONN4_BM04B-SRSS_JST; CONN4_BM04B-SRSS_JST
IC1: LIS3MDL; LGA12_2X2MM
IC3: WM8960; QFN32_5MM
J1: SM03B-SRSS-TBCONN_SM03B-SRSS-TB_JST; CONN_SM03B-SRSS-TB_JST
J2: C393939; USB-C-16P
J3, J7: SM02B-SRSS-TB(LF)(SN)
J4, J5: BM04B-SRSS-TBCONN4_BM04B-SRSS_JST; CONN4_BM04B-SRSS_JST
J6, J8, J9, J10, J11: SM04B-SRSS-TBCONN_SM04B-SRSS-TB_JST; CONN_SM04B-SRSS-TB_JST
L1: 6.8uH C36410; INDUCTOR_5X5MM_TDK_VLC5045
L3: FNR5012S100MT 10uH; IND_LQH5BPN2R2NT0L
LED2: LED_RED; LEDC1608X65N_RND-R
LED3: SYS_POW (19-213/Y2C-CQ2R2L/3T(CY)); LED-0603
LOW_BATT: LED_RED; LEDC1608X65N_RND-R
LS1: CMS-18138A-SP; CUI_CMS-18138A-SP
M.2KEYM(NGFF): 1-2199119-5 OR C841645; TE_1-2199119-5
OSC2: ECS-3225MV; OSC_3.2X2.5MM
Q1: SI1308EDL-T1-GE3; SOT65P210X110-3N
Q2: DMG2307L; SOT96P240X110-3N
Q3, Q4: NMOS_C7465427; SOT23
R1: 1.87M (TPA2005D1DRBR); RESC1005X40
R2: 340K (RTT053403FTP); RESC1005X40
R3: 1.87M; RESC1005X40
R4, R13, R36: 200K; RESC1005X40
R5, R14, R20, R23: 1K; RESC1005X40
R6: 590; RESC1005X40
R7: 1.1k; RESC1005X40
R8, R10, R34, R35: 1k; RESC1005X40
R9: 0.47; RESC1005X40
R11, R33, R43: 10K; RESC1005X40
R12: 0.01; 1206
R15, R18, R25, R26, R40, R42: 4.7K; RESC1005X40
R16, R17, R27, R28, R37, R39: 10k; RESC1005X40
R19: 5.1K; RESC1005X40
R21: 5.1k; RESC1005X40
R22: 180; RESC1005X40
R24: 100k; RESC1005X40
R29: 8.2k; RESC1005X40
R30: 36k; RESC1005X40
R31, R32: 27; RESC1005X40
R38: 4.7k; RESC1005X40
R41: 47K; RESC1005X40
R44: 6.57k; RESC1005X40
R46: 10K Trim; RTRIM3314J
R48, R49: 30k; RESC1005X40
RPI-CM1: DF40C-100DS-0.4V(51); RPI-CM4
RPIBOOT, RPIBOOT1, RPIBOOT2, RPIBOOT3, RPIBOOT4, RPIBOOT6, RPIBOOT8, RPIBOOT9, RPIBOOT10, RPIBOOT11, RPIBOOT12: DNP; PAD.03X.03
RPIBOOT5, RPIBOOT7: TEST-POINT3; PAD.03X.03
SJ1, SJ6: DNP; PAD-JUMPER-2-NC_BY_TRACE_YES_SILK
T1: MMUN2133LT1G; SC59-BEC
U1: TPS61092RSAR; PVQFN-16
U2: MC74VHC1G14DFT1G; SOT65P210X110-5N
U3: BQ27441DRZR-G1A; PDSO-N12
U4: BQ24075; PVQFN-N16
U5: MC74VHC1G14DFT1G OR C66196; SOT65P210X110-5N
U6: LSM6DS3; LGA-14L
U7: SN74LVC244ARWPRRWP0020A; RWP0020A
U8: PAM8302; MSOP8_0.65MM
U9: EMC2301-1-ACZL-TRMSOP8_MC_MCH-L; MSOP8_MC_MCH-L
U10, U11, U15: AP2112-3.3K; SOT23-5
U12: C233266; XDCR_SPU0410LR5H-QB
U13: TPD4EUSB30DQARDQA10; DQA10
U14: OPA344; SOT23-5
U16: W25Q16JVUXIQ_TR; PSON50P300X200X60-9N
U17, U18, U19, U20, U21, U22, U23, U24: TPD1E1B04DPYRDPY2_TEX; DPY2_TEX
U25: DRV2605LDGSR; SOP50P490X110-10N
U$120, U$123: MOUNTINGHOLE2.5; MOUNTINGHOLE_2.5_PLATED
USB2.0MUX: TS3USB30RSWR; 10-UFQFN
USB_BOOT_N: DNP; PAD.03X.03
Y1: ABM8-272-T3; ABM8272T3

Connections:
1V8BQ: C20.1, U3.5 (VDD)
2A3: U7.14 (2A3)
2A4: U7.16 (2A4)
2Y3: U7.4 (2Y3)
2Y4: U7.2 (2Y4)
3.3V: C28.1, C36.2, C49.1, CAMERA.22, D1.A, DISPLAY.22, IC1.5 (VDD), IC1.6 (VDDIO), IC3.8 (DCVDD), IC3.10 (DBVDD), OSC2.1 (INH), OSC2.4 (VCC), R15.2, R18.2, R30.2, R33.2, RPI-CM1.84 (CM4_3.3V(OUTPUT)), RPI-CM1.86 (CM4_3.3V(OUTPUT)), RPIBOOT2.P$1, SJ6.1, U2.5 (VCC), U6.5 (VDDIO), U6.8 (VDD), U9.3 (VDD)
3V3_EINK: C9.1, C17.1, EINK_524352471.9, EINK_524352471.10, L3.1, Q2.3 (D)
5.0V: C2.1, C6.1, C25.1, C39.1, C42.1, C54.1, C55.1, C59.1, C60.1, C61.1, C65.1, C66.1, IC3.21 (SPKVDD2), IC3.26 (SPKVDD1), J6.3, R3.2, R5.1, RPI-CM1.77 (+5V(INPUT)), RPI-CM1.79 (+5V(INPUT)), RPI-CM1.81 (+5V(INPUT)), RPI-CM1.83 (+5V(INPUT)), RPI-CM1.85 (+5V(INPUT)), RPI-CM1.87 (+5V(INPUT)), RPIBOOT1.P$1, U1.1 (VOUT), U1.15 (VOUT), U1.16 (VOUT), U8.1 (/SD), U8.6 (VDD), U10.1 (IN), U10.3 (EN)
!CE!: R24.1, U4.4 (!CE!)
!CHG!: J10.2, R22.2, U4.9 (!CHG!)
AGND: C67.2, C68.2, FB5.2, IC3.28 (AGND), IC3.33 (AGND)
AUDIO_MCLK: IC3.11 (MCLK), OSC2.3 (OUT)
AVDD: C50.1, C58.1, C67.1, C68.1, FB1.2, IC3.32 (AVDD), R27.2, U12.4 (VDD), U14.5 (P$V+)
BATTERY_IN: C19.1, J1.3, R12.2, U3.6 (BAT), U3.8 (SRP)
BOOST_EN: Q3.3 (D), R13.1, R36.2
BUTTON_D: BUD.2_1 (2), BUD.2_2 (2), C2040.29 (GPIO18), J11.3
BUTTON_S: BUS.2_1 (2), BUS.2_2 (2), C2040.27 (GPIO16)
BUTTON_U: BUP.2_1 (2), BUP.2_2 (2), C2040.28 (GPIO17), J11.2
CAM0_C_N: RPI-CM1.140 (CAM0_C_N)
CAM0_C_P: RPI-CM1.142 (CAM0_C_P)
CAM0_D0_N: RPI-CM1.128 (CAM0_D0_N)
CAM0_D0_P: RPI-CM1.130 (CAM0_D0_P)
CAM0_D1_N: RPI-CM1.134 (CAM0_D1_N)
CAM0_D1_P: RPI-CM1.136 (CAM0_D1_P)
CAM1_C_N: CAMERA.8, RPI-CM1.127 (CAM1_C_N)
CAM1_C_P: CAMERA.9, RPI-CM1.129 (CAM1_C_P)
CAM1_D0_N: CAMERA.2, RPI-CM1.115 (CAM1_D0_N)
CAM1_D0_P: CAMERA.3, RPI-CM1.117 (CAM1_D0_P)
CAM1_D1_N: CAMERA.5, RPI-CM1.121 (CAM1_D1_N)
CAM1_D1_P: CAMERA.6, RPI-CM1.123 (CAM1_D1_P)
CAM1_D2_N: CAMERA.11, RPI-CM1.133 (CAM1_D2_N)
CAM1_D2_P: CAMERA.12, RPI-CM1.135 (CAM1_D2_P)
CAM1_D3_N: CAMERA.14, RPI-CM1.139 (CAM1_D3_N)
CAM1_D3_P: CAMERA.15, RPI-CM1.141 (CAM1_D3_P)
CAM_GPIO: CAMERA.17, RPI-CM1.97 (CAMERA_GPIO)
CDD: C10.1, EINK_524352471.7
DSI0_C_N: RPI-CM1.169 (DSI0_C_N)
DSI0_C_P: RPI-CM1.171 (DSI0_C_P)
DSI0_D0_N: RPI-CM1.157 (DSI0_D0_N)
DSI0_D0_P: RPI-CM1.159 (DSI0_D0_P)
DSI0_D1_N: RPI-CM1.163 (DSI0_D1_N)
DSI0_D1_P: RPI-CM1.165 (DSI0_D1_P)
DSI1_C_N: DISPLAY.8, RPI-CM1.187 (DSI1_C_N)
DSI1_C_P: DISPLAY.9, RPI-CM1.189 (DSI1_C_P)
DSI1_D0_N: DISPLAY.2, RPI-CM1.175 (DSI1_D0_N)
DSI1_D0_P: DISPLAY.3, RPI-CM1.177 (DSI1_D0_P)
DSI1_D1_N: DISPLAY.5, RPI-CM1.181 (DSI1_D1_N)
DSI1_D1_P: DISPLAY.6, RPI-CM1.183 (DSI1_D1_P)
DSI1_D2_N: DISPLAY.11, RPI-CM1.193 (DSI1_D2_N)
DSI1_D2_P: DISPLAY.12, RPI-CM1.195 (DSI1_D2_P)
DSI1_D3_N: DISPLAY.14, RPI-CM1.194 (DSI1_D3_N)
DSI1_D3_P: DISPLAY.15, RPI-CM1.196 (DSI1_D3_P)
EINK_BUSY: C2040.13 (GPIO10), EINK_524352471.16, RPIBOOT9.P$1, U7.1 (1A1), U18.2 (I/O)
EINK_CS: C2040.16 (GPIO13), EINK_524352471.13, GND41.P$1, U7.11 (1Y4), U20.2 (I/O)
EINK_D/C: C2040.15 (GPIO12), EINK_524352471.14, RPIBOOT10.P$1, U7.13 (1Y3), U19.2 (I/O)
EINK_RESET: C2040.14 (GPIO11), EINK_524352471.15, GND40.P$1, U7.15 (1Y2), U17.2 (I/O)
ENABLE: R13.2, U1.11 (EN)
EXT_VCC_PCIE: M.2KEYM(NGFF).2, M.2KEYM(NGFF).4, M.2KEYM(NGFF).12, M.2KEYM(NGFF).14, M.2KEYM(NGFF).16, M.2KEYM(NGFF).18, M.2KEYM(NGFF).70, M.2KEYM(NGFF).72, M.2KEYM(NGFF).74, RPIBOOT3.P$1
FAN_PWM: J6.1, U9.5 (PWM)
GDR: EINK_524352471.23, Q1.1 (G), R11.2
GND: C1.2, C2.2, C3.2, C4.2, C5.2, C6.2, C7.2, C8.2, C9.2, C10.2, C11.2, C12.2, C13.2, C14.2, C15.2, C16.2, C17.2, C19.2, C20.2, C21.2, C22.2, C23.2, C24.1, C25.2, C26.2, C28.2, C30.2, C31.2, C32.2, C33.2, C34.1, C35.2, C36.1, C39.2, C40.2, C42.2, C43.2, C44.2, C45.2, C46.2, C47.2, C48.2, C49.2, C50.2, C52.2, C53.2, C54.2, C55.2, C57.2, C58.2, C59.2, C60.2, C61.2, C62.2, C63.2, C64.2, C65.2, C66.2, C69.2, C71.2, C72.2, C73.2, C74.2, C75.2, C76.2, C77.2, C79.2, C80.2, C82.2, C83.1, C2040.19 (TESTEN), C2040.57 (GND), CAMERA.1, CAMERA.4, CAMERA.7, CAMERA.10, CAMERA.13, CAMERA.16, CAMERA.19, CAMERA.P1, CAMERA.P2, D2.1 (K), DISPLAY.1, DISPLAY.4, DISPLAY.7, DISPLAY.10, DISPLAY.13, DISPLAY.16, DISPLAY.19, DISPLAY.P1, DISPLAY.P2, EINK_524352471.8, EINK_524352471.17, EINK_524352471.P1, EINK_524352471.P2, FB5.1, GND.P$1, GND13.P$1, GND22.P$1, GND26.P$1, GND27.P$1, GND34.P$1, IC1.2 (GND), IC1.3 (GND), IC1.9 (SDO), IC1.12 (GND), IC3.9 (DGND), IC3.20 (SPKGND2), IC3.24 (SPKGND1), J1.1, J2.GND, J2.GND2 (GND), J2.SHLD1 (SHLD), J2.SHLD2 (SHLD), J2.SHLD3 (SHLD), J2.SHLD4 (SHLD), J2.SHLD5 (SHLD), J2.SHLD6 (SHLD), J2.SHLD7 (SHLD), J2.SHLD8 (SHLD), J4.4, J5.3, J5.4, J6.4, J7.1, J8.3, J8.4, J9.4, J10.4, J11.4, LED2.C, LED3.C, LOW_BATT.C, M.2KEYM(NGFF).1, M.2KEYM(NGFF).3, M.2KEYM(NGFF).9, M.2KEYM(NGFF).15, M.2KEYM(NGFF).21, M.2KEYM(NGFF).27, M.2KEYM(NGFF).33, M.2KEYM(NGFF).39, M.2KEYM(NGFF).45, M.2KEYM(NGFF).51, M.2KEYM(NGFF).57, M.2KEYM(NGFF).71, M.2KEYM(NGFF).73, M.2KEYM(NGFF).75, M.2KEYM(NGFF).SH1 (SHIELD), M.2KEYM(NGFF).SH2 (SHIELD), OSC2.2 (GND), Q3.2 (S), Q4.2 (S), R2.1, R4.1, R6.2, R7.2, R9.1, R11.1, R14.2, R16.1, R17.1, R19.1, R21.1, R23.2, R24.2, R28.1, R37.1, R41.2, RPI-CM1.1 (GND), RPI-CM1.2 (GND), RPI-CM1.7 (GND), RPI-CM1.8 (GND), RPI-CM1.13 (GND), RPI-CM1.14 (GND), RPI-CM1.22 (GND), RPI-CM1.23 (GND), RPI-CM1.32 (GND), RPI-CM1.33 (GND), RPI-CM1.42 (GND), RPI-CM1.43 (GND), RPI-CM1.52 (GND), RPI-CM1.53 (GND), RPI-CM1.59 (GND), RPI-CM1.60 (GND), RPI-CM1.65 (GND), RPI-CM1.66 (GND), RPI-CM1.71 (GND), RPI-CM1.74 (GND), RPI-CM1.98 (GND), RPI-CM1.107 (GND), RPI-CM1.108 (GND), RPI-CM1.113 (GND), RPI-CM1.114 (GND), RPI-CM1.119 (GND), RPI-CM1.120 (GND), RPI-CM1.125 (GND), RPI-CM1.126 (GND), RPI-CM1.131 (GND), RPI-CM1.132 (GND), RPI-CM1.137 (GND), RPI-CM1.138 (GND), RPI-CM1.144 (GND), RPI-CM1.150 (GND), RPI-CM1.155 (GND), RPI-CM1.156 (GND), RPI-CM1.161 (GND), RPI-CM1.162 (GND), RPI-CM1.167 (GND), RPI-CM1.168 (GND), RPI-CM1.173 (GND), RPI-CM1.174 (GND), RPI-CM1.179 (GND), RPI-CM1.180 (GND), RPI-CM1.185 (GND), RPI-CM1.186 (GND), RPI-CM1.191 (GND), RPI-CM1.192 (GND), RPI-CM1.197 (GND), RPI-CM1.198 (GND), U1.5 (PGND), U1.6 (PGND), U1.7 (PGND), U1.10 (SYNC), U1.13 (GND), U1.P$18 (PGND), U1.P$19 (PGND), U1.P$20 (PGND), U1.P$21 (PGND), U1.P$22 (PGND), U1.THERMAL (PGND), U2.3 (GND), U3.3 (VSS), U3.EP (PWPD), U3.EP1 (PWPD), U3.EP2 (PWPD), U3.EP3 (PWPD), U3.EP4 (PWPD), U4.6 (EN1), U4.8 (VSS), U4.14 (TMR), U4.15 (SYSOFF), U4.EP, U5.3 (GND), U6.1 (SDO), U6.6 (GND)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
GND_2: U13.3 (GND_2)
GPOUT: R33.1, U3.12 (GPOUT)
HAP_3V3: C33.1, C35.1, U15.5 (OUT), U25.5 (EN), U25.6 (VDD/NC), U25.10 (VDD)
HDMI0_CEC: RPI-CM1.151 (HDMI0_CEC)
HDMI0_CLK_N: RPI-CM1.190 (HDMI0_CLK_N)
HDMI0_CLK_P: RPI-CM1.188 (HDMI0_CLK_P)
HDMI0_HOTPLUG: RPI-CM1.153 (HDMI0_HOTPLUG)
HDMI0_SCL: RPI-CM1.200 (HDMI0_SCL)
HDMI0_SDA: RPI-CM1.199 (HDMI0_SDA)
HDMI0_TX0_N: RPI-CM1.184 (HDMI0_TX0_N)
HDMI0_TX0_P: RPI-CM1.182 (HDMI0_TX0_P)
HDMI0_TX1_N: RPI-CM1.178 (HDMI0_TX1_N)
HDMI0_TX1_P: RPI-CM1.176 (HDMI0_TX1_P)
HDMI0_TX2_N: RPI-CM1.172 (HDMI0_TX2_N)
HDMI0_TX2_P: RPI-CM1.170 (HDMI0_TX2_P)
HDMI1_CEC: RPI-CM1.149 (HDMI1_CEC)
HDMI1_CLK_N: RPI-CM1.166 (HDMI1_CLK_N)
HDMI1_CLK_P: RPI-CM1.164 (HDMI1_CLK_P)
HDMI1_HOTPLUG: RPI-CM1.143 (HDMI1_HOTPLUG)
HDMI1_SCL: RPI-CM1.147 (HDMI1_SCL)
HDMI1_SDA: RPI-CM1.145 (HDMI1_SDA)
HDMI1_TX0_N: RPI-CM1.160 (HDMI1_TX0_N)
HDMI1_TX0_P: RPI-CM1.158 (HDMI1_TX0_P)
HDMI1_TX1_N: RPI-CM1.154 (HDMI1_TX1_N)
HDMI1_TX1_P: RPI-CM1.152 (HDMI1_TX1_P)
HDMI1_TX2_N: RPI-CM1.148 (HDMI1_TX2_N)
HDMI1_TX2_P: RPI-CM1.146 (HDMI1_TX2_P)
I2S_BCLK: IC3.12 (BCLK), RPI-CM1.49 (GPIO18)
I2S_DIN: IC3.16 (ADCDAT), RPI-CM1.27 (GPIO20)
I2S_DOUT: IC3.14 (DACDAT), RPI-CM1.25 (GPIO21)
I2S_LRCLK: IC3.13 (DACLRC), IC3.15 (ADCLRC/GPIO1), RPI-CM1.26 (GPIO19)
ILIM: R7.1, U4.12 (ILIM)
IN+: R48.2, U8.3 (IN_P)
IN-: R49.2, U8.4 (IN_N)
ISET: R6.1, U4.16 (ISET)
LBO: T1.B, U1.12 (LBO)
LEFT_N: C64.1, FB3.2, LS1.N
LEFT_P: C63.1, FB2.2, LS1.P
LINPUT1: IC3.4 (LINPUT1), J7.2
LOW_BATT_P: J10.3, R20.2, T1.C
MICBIAS: C46.1, C48.1, IC3.1 (MICBIAS)
unnamed: L1.P$2 (2), U1.3 (SW), U1.4 (SW)
unnamed: LOW_BATT.A, R20.1
unnamed: R1.1, R2.2, U1.9 (LBI)
unnamed: LED2.A, R5.2
unnamed: R3.1, R4.2, U1.14 (FB)
unnamed: RPI-CM1.78 (GPIO_VREF), SJ6.2
unnamed: C31.1, IC1.4 (C1)
unnamed: RPI-CM1.95 (PI_LED_!PWR), U2.2 (IN_A)
unnamed: C29.1, U12.1 (OUTPUT)
unnamed: LED3.A, R8.1
unnamed: C27.1, R38.1, R39.2, U14.4 (-IN)
unnamed: R10.2, RPI-CM1.21 (PI_!LED_ACTIVITY)
unnamed: D1.C, R10.1
unnamed: C34.2, U25.1 (REG)
unnamed: D5.C, R22.1
unnamed: D7.C, R14.1
unnamed: C18.1, D2.2 (A), D3.1 (K)
unnamed: C29.2, R38.2
unnamed: D6.C, R23.1
unnamed: C30.1, R27.1, R37.2, U14.3 (+IN)
unnamed: C18.2, D4.2 (A), L3.2, Q1.3 (D)
unnamed: Q4.3 (D), R34.2, USB_BOOT_N.P$1
unnamed: C38.2, R49.1
unnamed: C83.2, R35.2, Y1.3 (CRYSTAL_2)
unnamed: J2.B5 (CC2), R21.2
unnamed: Q2.1 (G), R43.2, R44.1
unnamed: R44.2, U5.4 (OUT_~Y)
unnamed: J2.A5 (CC1), R19.2
unnamed: C37.2, R48.1
unnamed: C37.1, R29.2, R46.3 (A)
NC: EINK_524352471.24
N_RPIBOOT: RPI-CM1.93 (!RPIBOOT), RPIBOOT.P$1
OUT: C62.1, C69.1, FB1.1, U10.5 (OUT)
OUT+: FB7.1, U8.5 (VO_P)
OUT-: FB4.1, U8.8 (VO_N)
PCIE_!RST: M.2KEYM(NGFF).50, RPI-CM1.109 (PCIE_!RST)
PCIE_CLK_!REQ: M.2KEYM(NGFF).52, RPI-CM1.102 (PCIE_CLK_!REQ)
PCIE_CLK_N: M.2KEYM(NGFF).53, RPI-CM1.112 (PCIE_CLK_N)
PCIE_CLK_P: M.2KEYM(NGFF).55, RPI-CM1.110 (PCIE_CLK_P)
PCIE_RX_N: M.2KEYM(NGFF).41, RPI-CM1.118 (PCIE_RX_N)
PCIE_RX_P: M.2KEYM(NGFF).43, RPI-CM1.116 (PCIE_RX_P)
PCIE_TX_N: M.2KEYM(NGFF).47, RPI-CM1.124 (PCIE_TX_N)
PCIE_TX_P: M.2KEYM(NGFF).49, RPI-CM1.122 (PCIE_TX_P)
PI_1V8: RPI-CM1.88 (CM4_1.8V(OUTPUT)), RPI-CM1.90 (CM4_1.8V(OUTPUT))
PI_PWR_INDICATE: R8.2, U2.4 (OUT_~Y)
PREVGH: C16.1, D4.1 (K), EINK_524352471.4
PREVGL: C14.1, D3.2 (A), EINK_524352471.2
RESE: EINK_524352471.22, Q1.2 (S), R9.2
RESERVED@104: RPI-CM1.104 (RESERVED)
RESERVED@106: RPI-CM1.106 (RESERVED)
RINPUT1: C27.2, IC3.5 (RINPUT1), R39.1, U14.1 (OUT)
SAM_1V1: C76.1, C77.1, C2040.23 (DVDD_2), C2040.45 (VREG_VOUT), C2040.50 (DVDD)
SAM_3V3: BUD.1_1 (1), BUD.1_2 (1), BUP.1_1 (1), BUP.1_2 (1), BUS.1_1 (1), BUS.1_2 (1), C7.1, C24.2, C43.1, C44.1, C71.1, C72.1, C73.1, C74.1, C75.1, C80.1, C2040.1 (IOVDD_2), C2040.10 (IOVDD_3), C2040.22 (IOVDD_4), C2040.33 (IOVDD_5), C2040.42 (IOVDD_6), C2040.43 (ADC_AVDD), C2040.44 (VREG_VIN), C2040.48 (USB_VDD), C2040.49 (IOVDD), D7.A, J4.1, J11.1, Q2.2 (S), R16.2, R17.2, R25.2, R26.2, R28.2, R40.2, R42.2, R43.1, U5.5 (VCC), U7.19 (VCC), U11.5 (OUT), U16.8 (VCC), USB2.0MUX.9 (VCC)
SAM_BOOT: Q4.1 (G), RPI-CM1.29 (GPIO16)
SAM_EINK_PWR: C2040.12 (GPIO9), U5.2 (IN_A)
SAM_EINK_SWITCH: C2040.34 (GPIO22), U7.18 (2OE_N), U7.20 (1OE_N)
SAM_GPIO3: C2040.5 (GPIO3)
SAM_GPIO4: C2040.6 (GPIO4)
SAM_GPIO5: C2040.7 (GPIO5)
SAM_GPIO6: C2040.8 (GPIO6)
SAM_GPIO7: C2040.9 (GPIO7)
SAM_GPIO8: C2040.11 (GPIO8)
SAM_GPIO23: C2040.35 (GPIO23)
SAM_GPIO26/ADC0: C2040.38 (GPIO26/ADC0)
SAM_GPIO27/ADC1: C2040.39 (GPIO27/ADC1)
SAM_GPIO28/ADC2: C2040.40 (GPIO28/ADC2)
SAM_GPIO29/ADC3: C2040.41 (GPIO29/ADC3)
SAM_INTERUPT: C2040.4 (GPIO2), RPI-CM1.46 (GPIO22), RPIBOOT12.P$1
SAM_QSPI_SCLK: C2040.52 (QSPI_SCLK), U16.6 (CLK)
SAM_QSPI_SCN: C2040.56 (QSPI_SCN), R34.1, U16.1 (!CS!)
SAM_QSPI_SD0: C2040.53 (QSPI_SD0), U16.5 (IO0)
SAM_QSPI_SD1: C2040.55 (QSPI_SD1), U16.2 (IO1)
SAM_QSPI_SD2: C2040.54 (QSPI_SD2), U16.3 (IO2)
SAM_QSPI_SD3: C2040.51 (QSPI_SD3), U16.7 (IO3)
SAM_RUN: C2040.26 (RUN)
SAM_SCL: C2040.37 (GPIO25), J4.3, R26.1, RPIBOOT8.P$1, U3.2 (SCL), U25.2 (SCL)
SAM_SDA: C2040.36 (GPIO24), GND37.P$1, J4.2, R25.1, U3.1 (SDA), U25.3 (SDA)
SAM_SWCLK: C2040.24 (SWCLK)
SAM_SWD: C2040.25 (SWD)
SAM_USB_DM: C2040.46 (USB_DM), R32.2
SAM_USB_DP: C2040.47 (USB_DP), R31.2
SAM_USB_SWITCH: C2040.30 (GPIO19), R41.1, USB2.0MUX.8 (~OE)
SAM_XIN: C82.1, C2040.20 (XIN), Y1.1 (CRYSTAL_1)
SAM_XOUT: C2040.21 (XOUT), R35.1
SCL0: CAMERA.20, DISPLAY.20, RPI-CM1.80 (SCL0)
SCL1: IC1.1 (SCL), IC3.17 (SCL), R18.1, RPI-CM1.56 (GPIO3), RPIBOOT6.P$1, U6.13 (SCL), U9.2 (SMCLK)
SDA0: CAMERA.21, DISPLAY.21, RPI-CM1.82 (SDA0)
SDA1: GND7.P$1, IC1.11 (SDA), IC3.18 (SDA), R15.1, RPI-CM1.58 (GPIO2), U6.14 (SDA), U9.1 (SMDATA)
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

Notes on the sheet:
Both grounds must be connected on the PCB at only one point close to the GND pin.
See Pg 15 1st para
6.8uH power w/2A current
R3 = 1.9Mohm for 5.2V R3 = 1.1Mohm for 3.3V
Sets fast charge current - R_ISET range: 590-8.9k - I_CHG = ~885 / R_ISET - EX: R_ISET = 590 : I_CHG = 1.5A
Sets combined system load and battery charge currents pulled from USB input. - I_INMAX=1650 / R_ILIM - R_ILIM range: 1.1k-8k - EX: R_ILIM = 1.1k : I_INMAX = 1.5A
BQ24075 - 1.5A USB-Friendly LiPo Battery Charger & Power-Path Management
BQ27441-G1 Fuel Gauge
SJ1: Cut to disable TS bypass.
SJ3: Cut to set custom ISET.
SJ4: Cut to set custom ILIM.
ILIM - System/Load Current Limit
ISET-Charge Current
TMR - Saftey Timers
Sets pre-charge and fast-charge safety timers. - Leave unconnected to set default (30min pre, 5hr charge time) - Connect to GND to disable - R_TMR range: 18k-72k - T_PRE range: 1400-2160 s - T_PRE (s) = 0.048 * R_TMR - T_MAX (s) = 10 * T_PRE
SJ2: Cut to enable charge timer.
TS - External Thermistor
- Connect TS to 10k NTC thermistor in the battery pack. - Connect a 10k resistor to GND if TS is not used.
VDD is 1.8V generated internally
OUT is the power-path management output. It manages current supplied from the USB input to both the battery and system. Or supplies battery power to the system when USB is not connected. OUT supply w/ USB: V_USB - 0.3V OUT supply w/o USB: V_BAT - 0.05V
I2C ADDR: 0x55
SJ5 sets the operation of the power LED. To either: - Power OUT indicator - !PGOOD! indicator (Good IN supply) - Open (LED disconnected)
5V BOOST
OE HIGH = Disconnected OE LOW = Connected S LOW = D1 S HIGH = D2
MOTION SUBSYSTEM
AUDIO SUBSYSTEM
POWER SUBSYSTEM
SOM
EINK_SUBSYSTEM
SAM
USB2.0
HAPTIC MOTOR
ACTIVE COOLING
DIGITAL PERIPHERAL
PCIE M.2
CAMERA MIPI 4 LANE
WARNING: MEMS MIC WILL BE DAMAGED BY ISOPRO
DISPLAY MIPI 4 LANE
*TOP CONTACT
ToDo: Ferrite (select w/high Z at high F, low Z at low F). Try to block everything >1MHz or so.

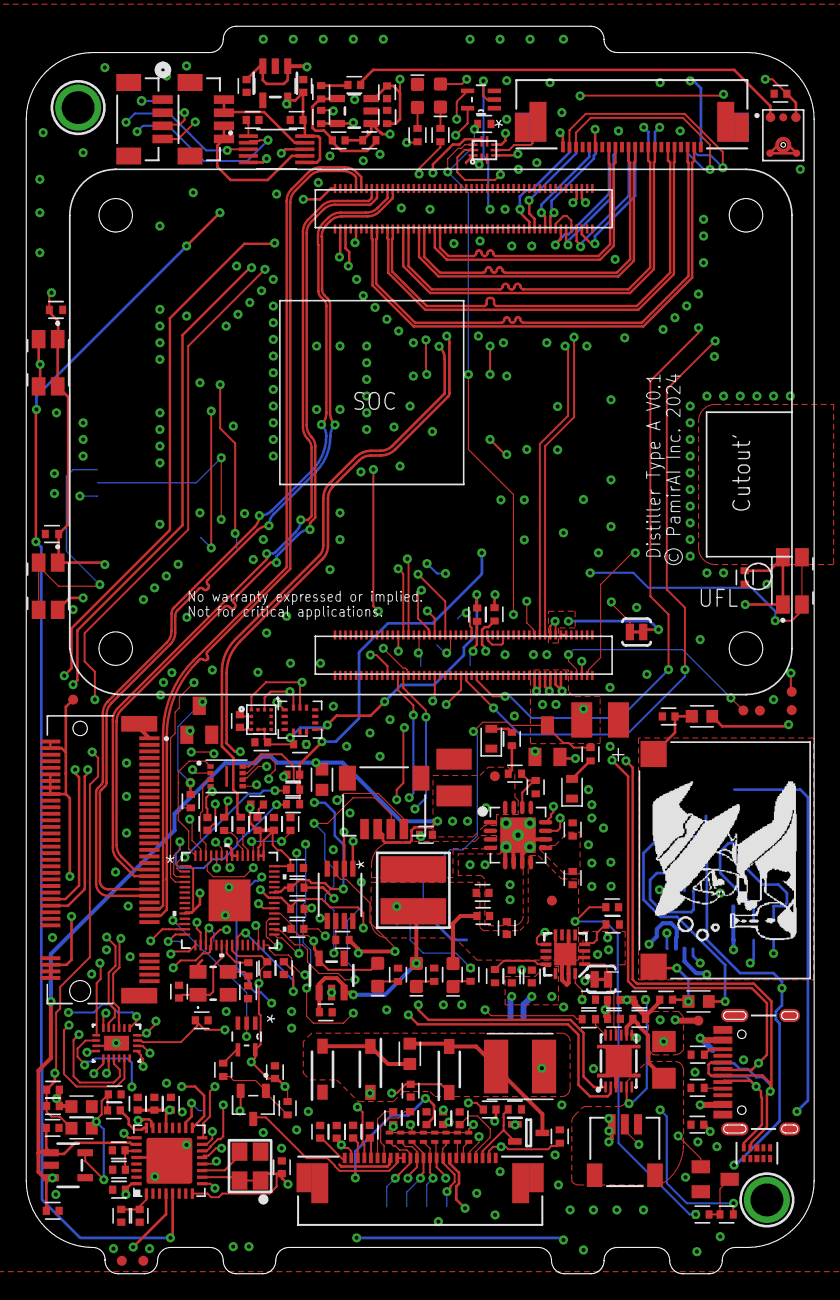
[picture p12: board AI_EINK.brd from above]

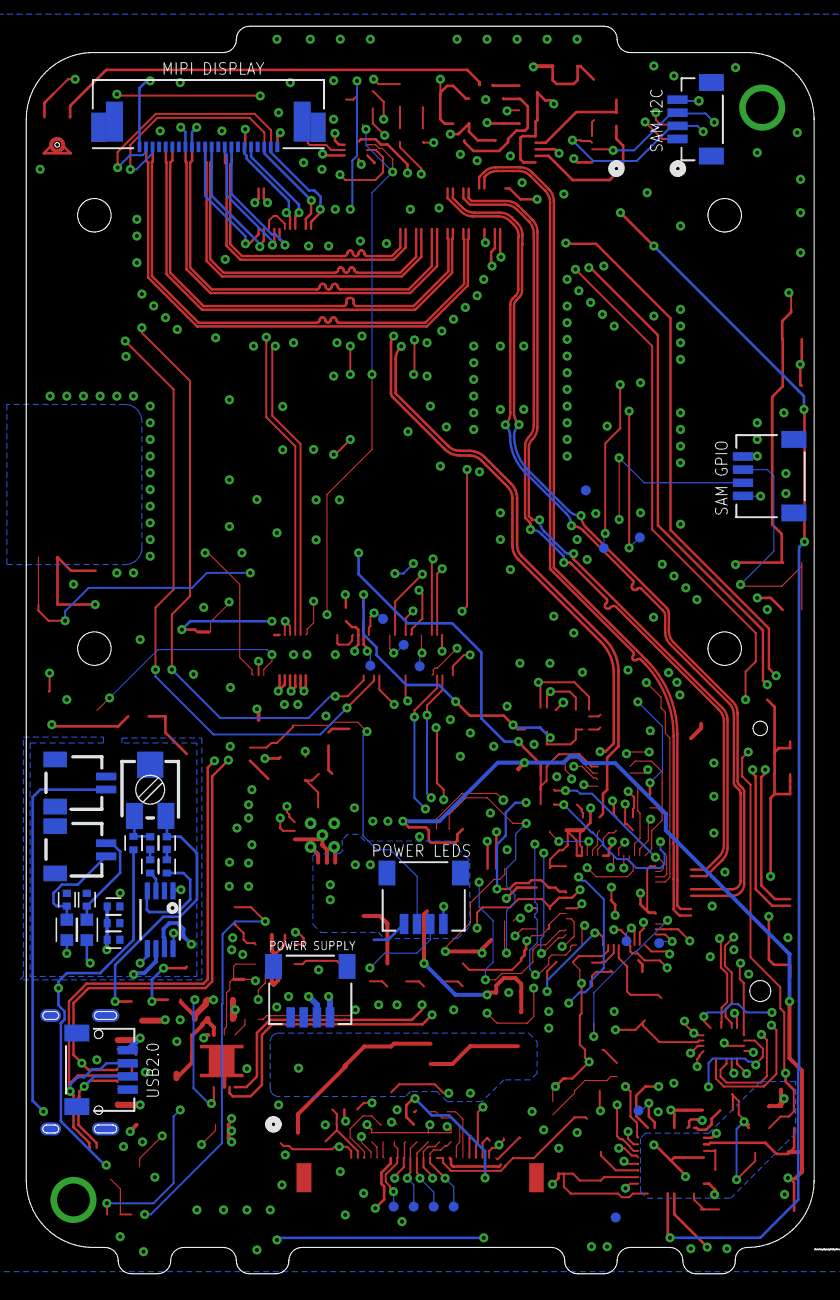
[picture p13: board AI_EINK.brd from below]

Board: 4 copper layers, 60.0 x 95.0 mm, 229 parts (37 on the bottom side), 170 nets.

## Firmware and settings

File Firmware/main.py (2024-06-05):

import machine
import utime
from eink_driver_sam import einkDSP_SAM
import _thread
from machine import WDT

#Instruction Set
EncodeTable = {"BTN_UP": 0b1, "BTN_DOWN": 0b10, "BTN_SELECT": 0b100, "SHUT_DOWN": 0b1000}

wdt = WDT(timeout=2000)
# Set up GPIO pins
selectBTN = machine.Pin(16, machine.Pin.IN, machine.Pin.PULL_DOWN)
upBTN = machine.Pin(17, machine.Pin.IN, machine.Pin.PULL_DOWN)
downBTN = machine.Pin(18, machine.Pin.IN, machine.Pin.PULL_DOWN)
powerStatus = machine.Pin(21, machine.Pin.OUT)
einkStatus = machine.Pin(9, machine.Pin.OUT)
sam_interrupt = machine.Pin(2, machine.Pin.OUT)

nukeUSB = machine.Pin(19, machine.Pin.OUT, value = 0)

# Setup UART0 on GPIO0 (TX) and GPIO1 (RX)
uart0 = machine.UART(0, baudrate=9600, tx=machine.Pin(0), rx=machine.Pin(1))
powerStatus.low()
einkStatus.low()

eink = einkDSP_SAM()

# Debounce time in milliseconds
debounce_time = 50

print("Starting...")

# Function to debounce button press
def debounce(pin):
    state = pin.value()
    utime.sleep_ms(debounce_time)
    if pin.value() != state:
        return False
    return True

def get_debounced_state(pin):
    return pin.value() and debounce(pin) 

def send_button_state():
    state_byte = 0
    state_byte |= get_debounced_state(selectBTN) * EncodeTable["BTN_SELECT"]
    state_byte |= get_debounced_state(upBTN)  * EncodeTable["BTN_UP"]
    state_byte |= get_debounced_state(downBTN) * EncodeTable["BTN_DOWN"]
    uart0.write(f"{state_byte}\n")

# Interrupt handler for down button
def button_handler(pin):
    if debounce(pin):
        send_button_state()

def loading_terminator(pin):
    global einkRunning
    if einkRunning:
        einkRunning = False
        eink.de_init()

# Set up interrupt handlers
selectBTN.irq(trigger=machine.Pin.IRQ_RISING, handler=button_handler)
upBTN.irq(trigger=machine.Pin.IRQ_RISING, handler=button_handler)
downBTN.irq(trigger=machine.Pin.IRQ_RISING, handler=button_handler)
sam_interrupt.irq(trigger=machine.Pin.IRQ_RISING, handler=loading_terminator)

einkRunning = False

def eink_task():
    global einkRunning  # Declare einkRunning as a global variable
    repeat = 0
    try:
        if eink.init == False:
            eink.re_init()
        eink.epd_init()
        eink.PIC_clear()
        while einkRunning and repeat < 3:
            eink.epd_init_part()
            eink.PIC_display('./loading1.bin', './loading2.bin')
            eink.epd_init_part()
            eink.PIC_display('./loading2.bin', './loading1.bin')
            wdt.feed()
            repeat += 1
        eink.de_init()
        einkRunning = False
        print("Eink Task Returned")
    except Exception as e:
        print(f"Exception {e}")
        eink.de_init()
        einkRunning = False

def delayed_power_off():
    global powerStatus
    global einkStatus
    global nukeUSB
    global einkRunning
    start_time = utime.ticks_ms()
    while utime.ticks_diff(utime.ticks_ms(), start_time) < 4000:
        utime.sleep_ms(10)
    powerStatus.low()
    einkStatus.low()  # inverted logic
    nukeUSB.low()

    try:
        if eink.init == False:
            eink.re_init()
        eink.epd_init_fast()
        eink.PIC_clear()
        eink.de_init()
        einkRunning = False
        print("Eink Task Returned")
    except Exception as e:
        print(f"Exception {e}")
        eink.de_init()
        einkRunning = False

while True:
    wdt.feed()
    if powerStatus.value() == 1 and uart0.any():
        data = str(uart0.readline()).strip()  # Read a line of data from the UART
        uart0.write(f"xSAM_INFO: {int(data)}\n")
        try:
            if int(data) == 15:  # Check if the received value matches 0b1111
                _thread.start_new_thread(delayed_power_off, ())
        except ValueError:
            print("Received non-binary data or malformed data")

    if debounce(selectBTN) and selectBTN.value() == 1 and upBTN.value() == 0 and downBTN.value() == 0:
        start_time = utime.ticks_ms()
        while utime.ticks_diff(utime.ticks_ms(), start_time) < 2000:
            if selectBTN.value() == 0:
                break
            wdt.feed()
            utime.sleep_ms(10)
        if utime.ticks_diff(utime.ticks_ms(), start_time) >= 2000 and powerStatus.value() == 0:
            powerStatus.high()
            einkStatus.high()  # inverted logic
            uart0.write("xPOWER_ON\n")
            nukeUSB.high()
            # Turn on the power on loading screen
            if einkRunning == False:
                try:
                    einkRunning = True
                    _thread.start_new_thread(eink_task, ())
                    print("Non Blocking")
                except Exception as e:
                    print(f"Exception {e}")
                    eink.de_init()
                    einkRunning = False

    
    if debounce(upBTN) and selectBTN.value() == 1:
        start_time = utime.ticks_ms()
        while utime.ticks_diff(utime.ticks_ms(), start_time) < 10000:
            if upBTN.value() == 0 or selectBTN.value() == 0:
                break
            if utime.ticks_diff(utime.ticks_ms(), start_time) >= 2000:
                uart0.write(f"{EncodeTable['SHUT_DOWN']}\n")
            wdt.feed()
            utime.sleep_ms(10)
        if utime.ticks_diff(utime.ticks_ms(), start_time) >= 10000 and powerStatus.value() == 1:
            powerStatus.low()
            einkStatus.low()  # inverted logic
            uart0.write("xFORCE_POWER_OFF\n")
            nukeUSB.low()
            einkRunning = False

    utime.sleep_ms(1)

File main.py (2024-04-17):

import asyncio
from einkDSP import einkDSP
from encoder import *
from GUI import *
from utils import *
import subprocess  # Import subprocess module
from Drivers.SAM.sam import SAM
import logging
logging.basicConfig(level=logging.INFO, format='%(asctime)s - %(levelname)s - %(message)s')

class Page:
    def __init__(self, app):
        self.app = app

    async def display(self):
        """Async method to define how the page displays itself."""
        pass

    async def handle_input(self, input):
        """Async method to handle user input."""
        pass


class HomePage(Page):
    
    def __init__(self, app):
        super().__init__(app)
        self.index = 0
        self.gui = GUI()
        self.display()
        self.subprogram = ['./app_tiny_diffusion.py', './app_ebook.py', './app_tamago.py', './app_ebook_kid.py']  # Add all your scripts here
        
    def handle_input(self, input):
        logging.info(f"handle_input {input}")
        if input == 0:
            last = self.index
            self.index = (self.index - 1) % len(self.gui.contents)
            self.gui.updateIndex(self.index, last)
            self.display()
        elif input == 1:
            last = self.index
            self.index = (self.index + 1) % len(self.gui.contents)
            self.gui.updateIndex(self.index, last)
            self.display()
        elif input == 2:
            if 0 <= self.index < len(self.subprogram):
                script_to_run = self.subprogram[self.index]
                logging.info(f'Executing script: {script_to_run}')
                # Run the script and wait for it to complete
                # self.app.multi_button_monitor.stop_monitoring()
                self._print_text("opening...")
                process = subprocess.Popen(['venv/bin/python', script_to_run],)
                process.wait()  # Wait for the subprocess to complete       
                # self.app.multi_button_monitor.start_monitoring()
                print("Sub-Program exited!!!")
                self.app.eink_init()
                self.display()
        else:
            pass
    
    def display(self):
        logging.info('home page display called')
        hex_pixels = dump_1bit(np.array(self.gui.canvas.transpose(Image.FLIP_TOP_BOTTOM), dtype=np.uint8))
        self.app.eink_display_2g(hex_pixels)

    def _print_text(self, text):
        image = fast_text_display(self.gui.canvas, text)
        hex_pixels = dump_1bit(np.array(image.transpose(Image.FLIP_TOP_BOTTOM), dtype=np.uint8))
        self.app.eink_display_2g(hex_pixels)

# Implement other ProgramPage classes similarly with async methods

class Application:
    def __init__(self):
        self.eink = einkDSP()
        self.eink.epd_init_fast()
        self.eink.PIC_display_Clear()
        self.in_4g = False
        self.current_page = HomePage(self)
        self.sam = SAM(self.press_callback)        


    def eink_display_4g(self, hex_pixels):
        logging.info('eink_display_4g')
        self.eink.epd_w21_init_4g()
        self.eink.pic_display_4g(hex_pixels)
        self.eink.epd_sleep()
        self.in_4g = True
    
    def eink_init(self):
        self.eink.epd_init_fast()
        self.eink.PIC_display_Clear()

    def eink_display_2g(self, hex_pixels):
        logging.info('eink_display_2g')
        if self.in_4g : 
            self.transit()
            self.in_4g = False

        self.eink.epd_init_part()
        self.eink.PIC_display(hex_pixels)

    def transit(self):
        self.eink.epd_init_fast()
        self.eink.PIC_display_Clear()
        
    def press_callback(self, key):
        self.current_page.handle_input(key)

async def main():
    app = Application()
    while True:
        print("Main.py Pring...")
        await asyncio.sleep(1)  # Sleep for a bit to yield control to the event loop

if __name__ == "__main__":
    asyncio.run(main())

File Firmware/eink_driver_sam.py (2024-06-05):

import machine
import utime
#TODO unblock the eink await 

class einkDSP_SAM:
    def __init__(self) -> None:
        self.oldData = 0x00

        # Pin Definition
        self.DC_PIN = machine.Pin(12, machine.Pin.OUT)
        self.RST_PIN = machine.Pin(11, machine.Pin.OUT)
        self.BUSY_PIN = machine.Pin(10, machine.Pin.IN, machine.Pin.PULL_UP)

        self.EPD_WIDTH = 240
        self.EPD_HEIGHT = 416
    
        # Initialize SPI
        
        self.spi = machine.SPI(1,baudrate=25000000,sck=machine.Pin(14, machine.Pin.OUT), mosi=machine.Pin(15, machine.Pin.OUT), miso=machine.Pin(8, machine.Pin.OUT))
        self.cs = machine.Pin(13, mode=machine.Pin.OUT, value=1)
        self.init = True
        self.watchdogCounter = 0
    
    def de_init(self):
        self.spi.deinit()
        self.DC_PIN = machine.Pin(12, machine.Pin.IN, None)
        self.RST_PIN = machine.Pin(11, machine.Pin.IN, None)
        self.BUSY_PIN = machine.Pin(10, machine.Pin.IN, None)
        self.cs = machine.Pin(13, machine.Pin.IN, None)
        machine.Pin(14, machine.Pin.IN, None)
        machine.Pin(15, machine.Pin.IN, None)
        machine.Pin(8, machine.Pin.IN, None)


        self.init = False
            
    
    def re_init(self):
        self.DC_PIN = machine.Pin(12, machine.Pin.OUT)
        self.RST_PIN = machine.Pin(11, machine.Pin.OUT)
        self.BUSY_PIN = machine.Pin(10, machine.Pin.IN, machine.Pin.PULL_UP)

        self.spi = machine.SPI(1,baudrate=25000000,sck=machine.Pin(14, machine.Pin.OUT), mosi=machine.Pin(15, machine.Pin.OUT), miso=machine.Pin(8, machine.Pin.OUT))
        self.cs = machine.Pin(13, mode=machine.Pin.OUT, value=1) 
        self.init = True

   
    def SPI_Delay(self):
        utime.sleep_us(10)  # 10 microseconds

    def SPI_Write(self, value):
        self.cs.low()
        self.spi.write(bytearray([value]))
        self.cs.high()

    def epd_w21_write_cmd(self, command):
        self.SPI_Delay()
        self.DC_PIN.low()
        self.SPI_Write(command)

    def epd_w21_write_data(self, data):
        self.SPI_Delay()
        self.DC_PIN.high()
        self.SPI_Write(data)

    def delay_xms(self, xms):
        utime.sleep_us(xms*1000)

    def epd_w21_init(self):
        self.delay_xms(10)  # At least 10ms delay
        self.RST_PIN.low()
        self.delay_xms(20)
        self.RST_PIN.high()
        self.delay_xms(20)

   
    def EPD_Display(self,image):
        width = (self.EPD_WIDTH + 7) // 8
        height = self.EPD_HEIGHT

        self.epd_w21_write_cmd(0x10)
        for j in range(height):
            for i in range(width):
                self.epd_w21_write_data(image[i + j * width])

        self.epd_w21_write_cmd(0x13)
        for _ in range(height * width):
            self.epd_w21_write_data(0x00) 

        self.epd_w21_write_cmd(0x12)
        self.delay_xms(1)  # Necessary delay
        # You would need to implement self.lcd_chkstatus here

    def lcd_chkstatus(self):
        while self.BUSY_PIN.value() == 0 and self.watchdogCounter < 100:
            self.delay_xms(10)  # Wait 10ms before checking again
            self.watchdogCounter += 1
        print(f"counter: {self.watchdogCounter}")
        self.watchdogCounter = 0

    def epd_sleep(self):
        self.epd_w21_write_cmd(0x02)  # Power off
        self.lcd_chkstatus()  # Implement this to check the display's busy status
        
        self.epd_w21_write_cmd(0x07)  # Deep sleep
        self.epd_w21_write_data(0xA5)

    def epd_init(self):
        self.epd_w21_init()  # Reset the e-paper display
        
        self.epd_w21_write_cmd(0x04)  # Power on
        self.lcd_chkstatus()  # Implement this to check the display's busy status

        self.epd_w21_write_cmd(0x50)  # VCOM and data interval setting
        self.epd_w21_write_data(0x97)  # Settings for your display

    def epd_init_fast(self):
        self.epd_w21_init()  # Reset the e-paper display
        
        self.epd_w21_write_cmd(0x04)  # Power on
        self.lcd_chkstatus()  # Implement this to check the display's busy status

        self.epd_w21_write_cmd(0xE0)
        self.epd_w21_write_data(0x02)

        self.epd_w21_write_cmd(0xE5)
        self.epd_w21_write_data(0x5A)

    def epd_init_part(self):
        self.epd_w21_init()  # Reset the e-paper display
        
        self.epd_w21_write_cmd(0x04)  # Power on
        self.lcd_chkstatus()  # Implement this to check the display's busy status

        self.epd_w21_write_cmd(0xE0)
        self.epd_w21_write_data(0x02)

        self.epd_w21_write_cmd(0xE5)
        self.epd_w21_write_data(0x6E)

        self.epd_w21_write_cmd(0x50)
        self.epd_w21_write_data(0xD7)

    def power_off(self):
        self.epd_w21_write_cmd(0x02)
        self.lcd_chkstatus()

    def PIC_display(self, old_file_path, file_path):
        # Assuming oldData is properly initialized and accessible
    
        # Transfer old data
        self.epd_w21_write_cmd(0x10)
        self.DC_PIN.on()  # Data mode

        if old_file_path is not None:
            with open(old_file_path, 'rb') as file:
                byte = file.read(1)
                while byte:
                    self.cs.low()
                    self.spi.write(bytes(byte))  # Convert each byte to bytearray for SPI
                    self.cs.high()
                    byte = file.read(1)
                    utime.sleep_us(10)
        else:
            for _ in range(0,(self.EPD_WIDTH * self.EPD_HEIGHT) // 8):
                self.cs.low()
                self.spi.write(bytes(0xFF))  # Convert data to bytes before sending
                self.cs.high()
                utime.sleep_us(1)


        # Transfer new data
        self.epd_w21_write_cmd(0x13)
        self.DC_PIN.on()  # Data mode          
        count = 0
        with open(file_path, 'rb') as file:
            byte = file.read(1)
            while byte:
                self.cs.low()
                self.spi.write(bytes(byte))  # Convert each byte to bytearray for SPI
                self.cs.high()
                byte = file.read(1)
                utime.sleep_us(10)
                count += 1
                # print(str(byte))
        print(count)

        # self.oldData = new_data[:]  # Copying data, ensure this is appropriate for your memory constraints

        # Refresh display
        self.epd_w21_write_cmd(0x12)
        self.delay_xms(1)  # Necessary delay for the display refresh
        self.lcd_chkstatus()  # Check if the display is ready
    
    def PIC_clear(self):
        # Assuming oldData is properly initialized and accessible
    
        # Transfer old data
        self.epd_w21_write_cmd(0x10)
        self.DC_PIN.on()  # Data mode

      
        for _ in range(0,(self.EPD_WIDTH * self.EPD_HEIGHT) // 8):
            self.cs.low()
            self.spi.write(bytes(0x00))  # Convert data to bytes before sending
            self.cs.high()
            utime.sleep_us(1)
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

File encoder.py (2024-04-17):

# Class to monitor a rotary encoder and update a value.  You can either read the value when you need it, by calling getValue(), or
# you can configure a callback which will be called whenever the value changes.
import os
import sys
import RPi.GPIO as GPIO
import time 
import threading
import concurrent.futures

class Encoder:

    def __init__(self, leftPin, rightPin, callback=None):
        self.leftPin = leftPin
        self.rightPin = rightPin
        self.counter = 0
        self.state = '00'
        self.direction = None
        self.callback = callback
        self.GPIO = GPIO
        self.GPIO.setmode(GPIO.BCM)
        self.GPIO.setup(self.leftPin, GPIO.IN, pull_up_down=GPIO.PUD_UP)
        self.GPIO.setup(self.rightPin, GPIO.IN, pull_up_down=GPIO.PUD_UP)
        self.GPIO.add_event_detect(self.leftPin, GPIO.BOTH, callback=self.transitionOccurred, bouncetime=200)  
        # GPIO.add_event_detect(self.rightPin, GPIO.RISING, callback=self.transitionOccurred,  bouncetime=2)  

    def transitionOccurred(self, channel):
        # time.sleep(0.002) # extra 2 mSec de-bounce time
        p1 = GPIO.input(self.leftPin)
        p2 = GPIO.input(self.rightPin)
        newState = "{}{}".format(p1, p2)
        print(f"p1 {p1} p2 {p2}")
        # reject bounce
        if self.state == "01" or self.state == "10" and newState == "00":
            self.state = newState
            return

        if newState == "00" or newState ==  "11": # down
            self.direction = "D"
            self.counter += 1
        else:
            self.direction = "U"
            self.counter -=1
        self.state = newState
        if self.callback : self.callback(self.counter, self.direction)
        return


    def getValue(self):
        return self.value



class Button:

    def __init__(self, Pin, direction=None, callback=None):
        self.Pin = Pin
        self.direction = direction
        self.callback = callback
        self.last_state = None
        self.last_call = time.time()
        GPIO.setmode(GPIO.BCM)
        GPIO.setup(self.Pin, GPIO.IN, pull_up_down=GPIO.PUD_DOWN)
        # GPIO.add_event_detect(self.Pin, GPIO.BOTH, callback=self.transitionOccurred)  
        time.sleep(1)
        self.thread = threading.Thread(target=self.monitor_pin)
        self.thread.daemon = True  # Ensure thread exits when main program does
        self.running = True
        self.thread.start()

    def monitor_pin(self):
        while self.running:
            current_state = GPIO.input(self.Pin)
            if current_state != self.last_state:
                self.transitionOccurred()
                self.last_state = current_state
            time.sleep(0.1)  # Adjust for sensitivity vs CPU usage

    def transitionOccurred(self):
        # time.sleep(0.002) # extra 2 mSec de-bounce time
        p = GPIO.input(self.Pin)
        self.state = p
        # print(p)
        if p == 1:
            ellapse_t = time.time() - self.last_call
            self.last_call = time.time()
            print("ellapse_t", ellapse_t)
            if ellapse_t < 0.1: # reject noise
                return
            if ellapse_t < 0.5: # double click
                # self.callback(1)
                # self.shut_down()
                return 
           

        if self.callback and p == 1:
            print(f'{self.direction} pressed') 
            self.callback(self.direction)
        return

    def getValue(self):
        return self.value

    def shut_down(self):
        print('terminating ... ')
        # raise SystemExit
        os.system("pkill -f " + sys.argv[0])



class MultiButtonMonitor:
    def __init__(self, buttons):
        """
        buttons: A list of dictionaries, where each dictionary contains:
                 'pin': The GPIO pin number,
                 'direction': A descriptive string for the button,
                 'callback': A function to call when the button is pressed.
        """
        self.buttons = buttons
        self.GPIO = GPIO
        for button in self.buttons:
            button['last_state'] = None
            button['last_call'] = time.time()
            self.GPIO.setmode(GPIO.BCM)
            self.GPIO.setup(button['pin'], GPIO.IN, pull_up_down=GPIO.PUD_DOWN)
            time.sleep(0.1)  # Adjust for sensitivity vs CPU usage
        
        self.running = False
        self.monitor_thread = None
        self.start_monitoring()
    
    def start_monitoring(self):
        if self.monitor_thread is None or not self.monitor_thread.is_alive():
            self.running = True
            self.monitor_thread = threading.Thread(target=self.monitor_pins)
            self.monitor_thread.daemon = True
            self.monitor_thread.start()

    def monitor_pins(self):
        try:
            while self.running:
                for button in self.buttons:
                    time.sleep(0.1)  # Adjust for sensitivity vs CPU usage
                    self.monitor_pin(button)
                    
                time.sleep(0.1)  # Adjust for sensitivity vs CPU usage
        except Exception as e:
            print(f"An exception occurred in monitor_pins thread: {e}")
            # Handle the exception, log it, or clean up resources here

    def monitor_pin(self, button):
        current_state = self.GPIO.input(button['pin'])
        if current_state != button['last_state']:
            self.transitionOccurred(button, current_state)
            button['last_state'] = current_state

    def transitionOccurred(self, button, p):
        print('pressed', p)
        if p == 1:
            # button clicked, check for exit condition
            if button['pin'] == 17 \
            and self.buttons[1]['last_state'] == 1 \
            and time.time() - self.buttons[1]['last_call'] > 6 : # down button pressed && more than 6 sec $$ this is enter button then exit
                self.shut_down()
                return

            ellapse_t = time.time() - button['last_call']
            button['last_call'] = time.time()
            print("ellapse_t", ellapse_t)
            if ellapse_t < 0.1: # reject noise
                return

            # if button['last_state'] == p and (current_time - button['pressed_time']) > 6:
            #     print("Shutting down due to long press...")
            #     self.shut_down()
            #     return


        button['last_state'] = p  # Update last_state to current state

        if button['callback'] and p == 1:
            print(f"{button['direction']} pressed")
            button['callback'](button['direction'])
        return

    def stop_monitoring(self):
        self.running = False
        if self.monitor_thread is not None and threading.current_thread() != self.monitor_thread:
            self.monitor_thread.join()

    def shut_down(self):
        print('Terminating ...')
        self.stop_monitoring()
        os.system("pkill -f " + sys.argv[0])

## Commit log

2024-02-18 skip chat and reduce sd step to 1
    [main.py]
2024-02-21 added PCB
    [AI_EINK.brd, AI_EINK.sch]
2024-02-21 added mic interface and RFID
    [AI_EINK.brd, AI_EINK.sch]
2024-03-03 switch random to np
2024-03-15 update ui button color
2024-03-27 pcb before downsize
    [AI_EINK.brd, AI_EINK.sch]
2024-03-28 kevin commit
    [AI_EINK.brd, AI_EINK.sch]
2024-03-30 PCB V3
    [AI_EINK.brd, AI_EINK.sch]
2024-04-04 pcb v4
    [AI_EINK.brd, AI_EINK.sch, AI_EINK_top_bom.csv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]
2024-04-17 add sam code
    [AI_EINK.brd]
2024-04-25 v5 PCB done
    [AI_EINK.brd, AI_EINK.sch, PowerButton.brd]
2024-05-06 cm5 rock eink driver integration
2024-07-02 before modification, v0.7, for fateen and adam
    [AI_EINK.brd, AI_EINK.sch, Mono Audio Amp.brd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]

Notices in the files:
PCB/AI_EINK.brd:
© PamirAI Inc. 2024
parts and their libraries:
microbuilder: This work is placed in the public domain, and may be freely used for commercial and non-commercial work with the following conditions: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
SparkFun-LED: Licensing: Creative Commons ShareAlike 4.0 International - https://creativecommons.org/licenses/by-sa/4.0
